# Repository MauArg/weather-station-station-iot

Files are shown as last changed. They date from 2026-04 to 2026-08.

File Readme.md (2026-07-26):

# Infraestructura — Weather Station

Stack de servicios que corre en la Raspberry Pi.

Link al anemómetro impreso en 3D = https://makerworld.com/en/models/2052859-the-windicator-v1

## Setup inicial (primera vez)

### 1. Variables de entorno
```bash
cp .env.example .env
nano .env   # completar MQTT_PASSWORD
```

### 2. Crear el archivo de passwords de Mosquitto
```bash
docker run --rm -it eclipse-mosquitto:2 \
  mosquitto_passwd -c /tmp/passwd weather \
  | cat > ./mosquitto/config/passwd
```

> ⚠️ `passwd` está en `.gitignore`. Nunca lo commitees — tiene credenciales en texto plano.

### 3. Levantar
```bash
docker compose up -d
```

### 4. Verificar que Mosquitto está funcionando
```bash
# En una terminal — escuchar todos los topics de la estación
docker exec -it mosquitto \
  mosquitto_sub -h localhost -u weather -P TU_PASSWORD -t "station/#" -v

# En otra terminal — publicar mensaje de prueba
docker exec -it mosquitto \
  mosquitto_pub -h localhost -u weather -P TU_PASSWORD \
  -t "station/01/test" -m "hola"
```

Si ves `station/01/test hola` en la primera terminal, el broker está listo.

---

## Operación

```bash
# Ver logs en tiempo real
docker compose logs -f mosquitto

# Reiniciar broker
docker compose restart mosquitto

# Bajar todo
docker compose down

# Bajar y eliminar volúmenes (⚠️ borra datos persistidos)
docker compose down -v
```

---

## Activar service mode en el ESP32

**Vía recomendada: la UI.** El dashboard tiene una vista de *service mode* (botón en la barra superior) que arma la sesión, detecta sola cuándo el nodo está despierto y escuchando, verifica la versión después del flash y desarma. Ver `weather-station-frontend-dashboard/`.

Ahí también están el visor de payloads en vivo, el estado por sensor, el margen del buffer MQTT y el indicador de batería con semáforo de riesgo de flasheo.

### Por línea de comandos (fallback si la UI o el backend están caídos)

```bash
# Desde la Raspberry Pi
docker exec -it mosquitto \
  mosquitto_pub -h localhost -u weather -P TU_PASSWORD \
  -t "station/01/cmd" -r \
  -m '{"cmd":"maintenance","timeout_min":15,"issued_at":"'$(date -u +%FT%TZ)'"}'
```

El ESP lo recibirá en el próximo ciclo de wake. Para saber cuándo está listo **no hace falta hacerle ping**: publica en `station/01/status` un `service_mode_active` al entrar y un `service_mode_alive` cada 30 s con el `remaining_sec`, así que alcanza con escuchar ese topic:

```bash
docker exec -it mosquitto \
  mosquitto_sub -h localhost -u weather -P TU_PASSWORD -t "station/01/status" -v
```

Una vez en service mode, flashear desde PlatformIO:
```bash
pio run -e ota_production -t upload     # el que va a campo (LOG_LEVEL=0)
pio run -e ota_development -t upload    # debug (LOG_LEVEL=2, paga 2 s por wake)
```

Y al terminar, **limpiar el retenido** — si no, el nodo se queda despierto hasta que venza el timeout:
```bash
docker exec -it mosquitto \
  mosquitto_pub -h localhost -u weather -P TU_PASSWORD -t "station/01/cmd" -r -m ''
```

---

## Pipeline completo de datos (actualizado 2026-07-11)

Los bloques de **InfluxDB** y **N8N** en `docker-compose.yml` están comentados porque esos servicios **ya están corriendo, pero no acá** — no en la Raspberry Pi de la estación, sino repartidos así:

```
ESP32 ──MQTT──▶ Mosquitto (Docker, esta RPi)
                      │
                      ▼
                 N8N (host de esta RPi, NO en Docker)
                 MQTT Trigger → Code (Line Protocol) → HTTP Request
                      │
                      ▼
              InfluxDB v2 (Docker, NAS 192.168.18.251)
                      │
                      ▼
                Grafana (Docker, NAS 192.168.18.251, puerto 3000)
```

- **NAS (192.168.18.251)**: InfluxDB v2 (imagen fijada a `influxdb:2` — **nunca** `influxdb:latest`, la v3 Core tiene ventana de consulta de 72h, inutilizable para histórico meteorológico) y Grafana, ambos en Docker sobre una red interna `iot-net`, con datos persistidos en `/mnt/disco/influxdb` y `/mnt/disco/grafana`. Hay un override de systemd (drop-in) que hace que Docker espere a que el mount NFS esté listo antes de arrancar — sin eso, los contenedores fallan en boot si el NFS tarda en montar.
- **N8N** corre directo en el host de esta Raspberry Pi (no dockerizado), no en el `docker-compose.yml` de este repo.

⚠️ Los `docker-compose.yml` / configuración del lado del NAS (InfluxDB, Grafana) todavía no están versionados en ningún repo de este proyecto — viven solo en el NAS. Pendiente de incorporar a git si se quiere que el NAS también sea reproducible desde acá.

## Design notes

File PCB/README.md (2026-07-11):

# PCB — exports de fabricación

Exports de fabricación (capas etch/copper/mask/silk en PDF, y SVG) para la PCB v2, generados desde los proyectos Fritzing en la raíz de este repo (`Main PCB - Estación Meteorológica - IoT_v1.4.fzz`, `Aux PCB - Estación Meteorológica - IoT_v1.2.2.fzz`).

Fabricadas caseramente: PCB FR4 simple faz, transferencia de tóner + cloruro férrico. Ver `../componentes_y_conexiones.md` → "PCB v2 — en fabricación" para el estado del armado y el layout completo (asignación de holes, GPIOs, conectores JST).

- `Main 1.4/` — placa principal (ESP32, INA219×2, step-up boost, switching de rails).
- `Aux 1.2/` — placa auxiliar de conectores JST.
- `Main 1.4/Intento1/`, `Main 1.4/Intento2/` — iteraciones sucesivas del export de fabricación de la placa principal.

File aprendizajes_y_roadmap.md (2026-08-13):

# Aprendizajes, decisiones y roadmap

> Migrado desde el proyecto legacy en la UI de Claude (Project Knowledge) el 2026-07-11. Contenido de diseño/ingeniería que no encaja en `componentes_y_conexiones.md` (estado actual de hardware) ni en `Readme.md` (operación de infra). Ver también `../STATUS.md` para el estado vivo resumido.

---

## Subsistema de viento (dirección) — en definición

**Anemómetro — resuelto y estable:**
Modelo base: [The Windicator V1](https://makerworld.com/en/models/2052859-the-windicator-v1) (MakerWorld) — diseño integrado anemómetro + veleta, 2× rodamientos 608ZZ. El eje interior es fijo; el cuerpo exterior (veleta) rota alrededor de él — **no al revés** (esto descarta cualquier approach de montaje de eje fijo para la veleta, ver abajo).

- Sensado: reed switch + 3 imanes (uno por brazo de cazoleta). Radio brazo = 130mm centro a centro.
- Debounce: 2ms (soporta hasta ~500 pulsos/s).
- Factor de calibración ≈ 0.218 m/pulso (2π × 0.130m × 0.8 eficiencia ÷ 3 imanes).
- GPIO2, interrupt.
- Diseño/calibración lista en papel — **pendiente armado mecánico y prueba en campo** (no se empezó todavía, ver `componentes_y_conexiones.md` → "Estado actual en campo").

**Dirección — AS5600 vuelve a ser candidato fuerte (actualizado 2026-07-25):**
La conclusión previa (imanes disponibles son axiales, incompatibles con el AS5600) queda corregida: el módulo AS5600 vino con un imán chico que no se había notado antes. Mau ya soldó los conectores dupont del módulo para probarlo en banco con un Arduino Mega — primero "a mano" (rotando el imán frente al sensor sin la veleta montada, mirando magnet-detected/AGC/magnitude por I2C) y después una prueba de concepto con la veleta montada. Todavía no está confirmado si ese imán es diametral o si el AS5600 tolera algo distinto de lo asumido originalmente — eso es justo lo que la prueba de banco va a determinar, no asumir el resultado.

Contexto original del problema, vigente como fallback si la prueba de banco no lo resuelve:
El approach con AS5600 (sensor de efecto Hall angular, I2C 0x36) requiere un imán **diametralmente magnetizado** (N/S en caras opuestas del disco). La conclusión anterior era que solo había imanes de magnetización **axial** disponibles (polos en las caras planas), y que conseguir uno diametral ~6mm N45 en Argentina (MercadoLibre, local) resultaba difícil. Un imán anillo con diámetro interior >8.25mm también es difícil de conseguir localmente.

**Alternativa (plan B si el AS5600 no resuelve en banco) — disco óptico Gray code:**
3× sensores IR reflectivos TCRT5000 (del kit Sunfounder "Tracking Sensor") sobre un disco con patrón Gray code. Da posición **absoluta** (8 posiciones, resolución 45°) inmediatamente al despertar de deep sleep — resuelve la limitación de posición relativa del AS5600 (que necesitaría recalibrar en cada wake). Operación pulsada (2ms cada 10s, duty cycle 0.02%) reduce el consumo promedio a ~0.018mA.

- GPIO expander PCF8574 (I2C 0x20, sin conflicto de bus) lee las 3 líneas digitales (P0–P2).
- GPIO20 controla LED_EN vía transistor BC337.
- Un segundo cable UTP (6 de los 8 pares: VCC, GND, DO1, DO2, DO3, LED_EN) va del Windicator a la caja estanca.
- Mau tiene 1 sensor TCRT5000; necesita 2 más (más fácil de conseguir localmente que el imán diametral).

---

## Aprendizajes técnicos (no cubiertos en otros documentos)

- **DHT11 (y por extensión DHT22) necesita ~1s de estabilización** después de encender Rail B antes de poder leer.
- **Boost converter → pin 5V del ESP32 es el path de alimentación correcto.** Conectar la batería directo a un LDO falló por voltaje de dropout insuficiente con una LiPo a 3.7V.
- **AS5600 no es compatible con el montaje de eje fijo del Windicator V1** — el diseño tiene el eje interior fijo y el cuerpo exterior rotando, lo inverso de lo que ese approach de montaje asume.
- **GitHub devuelve 404 (no 403) para repos privados sin autenticar** — no es una falla de red, hay que reconocerlo como "repo privado, necesita auth" en vez de reintentar la conexión.
- **Grafana: las variables "Constant"** requieren guardar el dashboard explícitamente para que el cambio se aplique.

- **El volumen de InfluxDB no es el recurso escaso; el barrido de consultas sí** (medido 2026-08-09, a raíz de la duda por el volumen que genera live mode). Con live corriendo 7 h en los días soleados el ritmo pasa de ~1.350 a ~5.760 payloads/día — **4,3×**, no 12×, porque live se auto-limita a las horas de excedente. A 26 campos y con la compresión TSM sobre floats de variación lenta son **~170 MB/año, ~1,7 GB en 10 años**: sobre el disco de 4 TB del NAS, 0,04%. Aunque la estimación se equivoque por 10×, sigue siendo irrelevante.

  Lo que sí escala mal con los años es **escanear millones de puntos de 5 s para un gráfico de rango largo**. El disparador a vigilar es ese, no el disco: **si un dashboard de rango largo empieza a tardar, la respuesta es una tarea de downsampling** (agregados de 1 min o 1 h para rangos largos, crudo sólo para lo reciente), no borrar datos ni achicar live mode. Hoy no hace falta.

  Dos cosas más del mismo relevamiento: la **retención del bucket es infinita**, que para una estación meteorológica es probablemente lo correcto —la serie histórica larga *es* el producto— pero conviene que sea una elección consciente. Y la **cardinalidad crece por el tag `firmware`**, una serie nueva por versión para siempre (28 al 2026-08-09). Irrelevante en capacidad —InfluxDB aguanta millones— pero es el tag que ya rompió cinco queries con `last()` devolviendo un resultado por serie; toda query nueva tiene que contemplarlo.

- **Un campo nuevo en la telemetría no aparece solo en InfluxDB.** El workflow de N8N arma Line Protocol desde un `fieldMap` explícito y descarta en silencio lo que no conoce. `log_active`/`log_count` existían desde el `1.3.0` y nunca llegaron; se descubrió recién en agosto al buscar `live_seq`. Ese script **no está versionado en ningún repo** (vive sólo en el NAS). Regla: al agregar un campo al payload, **decidir explícitamente** si va a N8N en la misma tanda. Detalle en `../STATUS.md`.

  La regla es decidir, no agregar todo: lo que hay que evitar es que un campo se pierda sin que nadie lo note, no que InfluxDB tenga todo. **Caso resuelto así (2026-08-09): `next_s` NO se agregó.** Lo consume el backend leyendo el payload MQTT directo, así que la funcionalidad no depende de InfluxDB; y como dato histórico es derivable (la presencia de `live_seq` ya marca la sesión, y los deltas entre timestamps dan la cadencia real, que además es más honesta que la intención del nodo) y vale 60 en el 99% de los puntos. **Reevaluarlo cuando lleguen los tiers**: ahí `next_s` pasa a valer 60/300/1800 según el voltaje del pack y deja de ser derivable de los otros campos.

- **Comparar una magnitud con ciclo diurno entre dos firmwares exige controlar la hora del día.** Al validar el cambio de `DHT_WARMUP_MS` el delta DHT22−DS18B20 parecía haberse corrido 0,3 °C; separando por franja horaria, el firmware **sin cambiar** daba lo mismo en esa franja. Era el transitorio de enfriamiento de la tarde, donde el DHT22 (masa térmica chica) sigue la caída más rápido que el DS18B20. Es el mismo error de método que ya se había cometido con la posición del sniffer WiFi, en otra dimensión.

- **El rollback de OTA está compilado pero desarmado, y `esp_ota_mark_app_valid_cancel_rollback()` no hace lo que parece.** `CONFIG_BOOTLOADER_APP_ROLLBACK_ENABLE=y` en el sdkconfig del core, o sea que una imagen recién flasheada arranca en `ESP_OTA_IMG_PENDING_VERIFY` y el bootloader la revertiría si nadie la valida. Pero el core de Arduino la valida solo: `initArduino()` (en `esp32-hal-misc.c`, antes de `setup()`) llama a `verifyOta()` —función *weak* que devuelve `true` por defecto— y marca la imagen válida. **Toda imagen que bootee se acepta sin chequear nada.** Además, la llamada que había en `ArduinoOTA.onEnd()` corría en el firmware *viejo* y marcaba válida la partición vieja, no la nueva; se eliminó.

  Lo que sí sigue protegido sin hacer nada: un flash **cortado a la mitad** deja una imagen que no pasa la validación del bootloader, y arranca la partición anterior. El agujero es la imagen **completa pero rota**, que bootea y se acepta.

  **Evaluado a fondo el 2026-07-27 — decisión: no se implementa por ahora.** El análisis quedó acá porque la conclusión no es obvia y no conviene re-derivarla.

  **`verifyOta()` es la palanca equivocada**, al contrario de lo que decía la nota original de este mismo bullet. Ese hook corre dentro de `initArduino()`, *antes* de `setup()`: sólo puede juzgar con lo que se sabe en el primer arranque de la imagen, cuando todavía no corrió nada del firmware. Un chequeo de I2C ahí responde "¿está el hardware?", no "¿sirve este firmware?". La palanca real es la otra función weak del mismo bloque, **`verifyRollbackLater()`**: devolviendo `true` el core saltea la validación entera y la decisión queda del lado de la aplicación, para tomarla más tarde con el runtime ya levantado. Ninguna de las dos está declarada en un header — son símbolos C, hay que definirlas con `extern "C"`.

  **El bloqueante que parecía haber, no existe.** `esp_ota_begin()` devuelve `ESP_ERR_OTA_ROLLBACK_INVALID_STATE` si la imagen corriendo está en `PENDING_VERIFY`, lo que dejaría una ventana de OTA abierta pero inútil. No aplica: el `Update` de Arduino no pasa por `esp_ota_begin()` — usa `esp_ota_get_next_update_partition()` + escritura cruda de partición + `esp_ota_set_boot_partition()` (`Updater.cpp`), y ese último no tiene ese código de error. **Con la imagen sin confirmar, el OTA sigue funcionando**, así que diferir la validación es seguro.

  **El criterio de salud no debería ser I2C** sino "la imagen llegó a abrir su propia ventana de OTA", con "llegó a dormir limpio" como red de contención. Las dos propiedades son locales y **un fallo de WiFi cuenta como sano**, que es lo que evita el falso positivo con el ~17% de ciclos que no conectan. Habría que confirmar en cinco puntos: después de `_setupOTA()` en `serviceMode_run()`, en `goToDeepSleep()`, en `serviceMode_exit()` (que llama a `esp_deep_sleep()` directo) y antes de los dos `ESP.restart()` — sin este último, un comando `reboot` durante la ventana sin confirmar dispararía un rollback. La llamada tiene que ir guardada detrás de un `esp_ota_get_state_partition() == ESP_OTA_IMG_PENDING_VERIFY` explícito: sin eso, cada deep sleep podría escribir en `otadata`, que son ~1440 escrituras/día sobre una partición de 8 KB.

  **Por qué no se implementa igual**: de los bugs reales que aparecieron en este firmware — loop de `reboot`, timeout de service mode que no acotaba, overflow del buffer MQTT, warmup del DHT que nunca corría — el rollback no habría atrapado **ninguno**; todos completaban un ciclo limpio. Sólo cubre "crashea antes de abrir el OTA", y como el post-OTA reintenta service mode en cada boot, la ventana real de brickeo es angosta (un crash en `Wire.begin()` o `connectWiFi()`). A cambio agrega un modo de falla insidioso: si un camino de salida nuevo se olvida de confirmar, el nodo revierte firmware solo, semanas después. El argumento a favor sigue siendo válido y es no-técnico — el plan B de un brickeo es subir al techo y **abrir la caja estanca**, el mismo sellado que se monitorea con el DHT22 — así que esto se reconsidera si el firmware se vuelve más riesgoso de flashear.

  **Sin verificar**: el sdkconfig tiene `CONFIG_BOOTLOADER_SKIP_VALIDATE_IN_DEEP_SLEEP=1` y no se pudo determinar offline si el chequeo de `PENDING_VERIFY` del bootloader corre al despertar de deep sleep (el paquete de PlatformIO trae sólo headers, no las fuentes del bootloader). El diseño de arriba está armado para no depender de eso, pero si se implementa hay que confirmarlo en banco.

(Los aprendizajes sobre I2C/pull-ups externos, `system_mW` no siendo consumo real, cold solder joints, InfluxDB `:2` fijo, y el drop-in de systemd para NFS ya están documentados en `componentes_y_conexiones.md`, `../i2c-bus-lockup-investigation.md` y `Readme.md` respectivamente.)

---

## Herramientas y recursos

- **Desarrollo:** VSCode + PlatformIO. Build flags ESP32-C3 SuperMini: `ARDUINO_USB_CDC_ON_BOOT=1`, `ARDUINO_USB_MODE=1`.
- **Pipeline de datos:** ver `Readme.md` → "Pipeline completo de datos".
- **Referencias de hardware:** kit Sunfounder (DHT11, DS18B20, raindrop sensor, fotoresistor, reed switch, TCRT5000 "Tracking Sensor", PCF8591 ADC); módulo MPPT CN3791; transistores NPN BC337; expansor I2C PCF8574; conectores Wago 221 lever; conectores JST XH; prensaestopas PG-7 y PG-9.
- **Sourcing:** Embalse, Córdoba, Argentina — ferreterías locales para mecánica, MercadoLibre para electrónica. Algunos componentes (imanes diametrales, imanes anillo) son difíciles de conseguir localmente.
- **Impresión 3D:** Mau no tiene impresora propia — depende de un familiar en Buenos Aires para las piezas impresas, lo que agrega tiempo de espera a cualquier pieza nueva.

---

## Roadmap — "en el horizonte"

Reconciliado con el estado real al 2026-07-11 (el snapshot original venía del proyecto legacy en la UI y estaba desactualizado en varios puntos — marcado abajo).

- ✅ **Armado físico del prototipo v1** — hecho (dos perfboards, con cold solder joints ya en gran parte resueltos). El snapshot original lo listaba como pendiente; ya no lo está.
- 🔄 **PCB v2 (FR4 casera, transferencia de tóner + cloruro férrico)** — en fabricación. Main + Aux perforadas, soldadura en curso. Pendiente: terminar de soldar, limpiar flux, enmascarar headers hembra, aplicar flux protector + barniz dielectrico, curar, recién ahí instalar módulos enchufables (INA219, ESP32). Ver `componentes_y_conexiones.md` → "PCB v2 — en fabricación".
- ✅ **Perforación de la caja estanca** (ventana PET para fotoresistor, prensaestopas) — hecha, sistema desplegado y operativo.
- ✅ **Backend + frontend custom** — hecho: `weather-station-backend-service` (Go) y `weather-station-frontend-dashboard` (React/Vite), ya no es "un amigo capaz hace el frontend" como decía el snapshot original.
- ⏳ **Resolución de dirección de viento** — AS5600 vuelve a ser candidato fuerte (imán chico encontrado en el módulo, no notado antes); en validación de banco con Arduino Mega desde 2026-07-25. Óptica (2 sensores TCRT5000 más) sigue como plan B.
- ⏳ **Armado mecánico del Windicator** (anemómetro + veleta) — impreso en PLA, pendiente de armar y probar en campo.
- ❓ **Montaje del panel solar** (placa de respaldo policarbonato/fenólico, sellado con silicona, bracket a 45°) — estado sin confirmar en esta sesión; el sistema ya reporta datos solares (INA219 solar) así que probablemente esté al menos parcialmente instalado.
- ❓ **Mejora del Stevenson screen** (protección lateral contra sol, ventilación forzada) — estado sin confirmar. Se sabe que el wrap de aluminio en el mástil redujo contaminación térmica (2.04°C de mejora confirmada por análisis de datos) pero generó un efecto espejo que refleja radiación hacia el BMP180.
- ⏳ **Modos adaptativos de firmware** (día/noche por voltaje solar, tiers de energía por voltaje de batería) — **verificado 2026-07-29: no está implementado.** `src/battery.h` existe pero está vacío (0 bytes), `SLEEP_INTERVAL_SEC` es fijo, y `sensors_railsOn()` enciende los dos rails incondicionalmente (el TODO sigue ahí). Los umbrales de `componentes_y_conexiones.md` son diseño en papel. **Corrección de premisa**: los tiers no ahorran en deep sleep — GPIO7/GPIO8 no son RTC GPIOs en el ESP32-C3, así que al dormir quedan sin drive y el pull-down de 9,9 kΩ corta ambos rails solo. El ahorro real está en T3/T4, que cambian el intervalo de sleep.
- ✅ **Bajo consumo — dos fixes en campo (2026-07-29)**: INA219 en power-down entre ciclos (`1.4.0`) y warmup del DHT22 en paralelo con la red (`1.5.0`). Ver `../STATUS.md` → "Power management".
- ⏳ **Calibración de lluvia en Grafana** — `rain_wet_ref=0.3` sigue siendo un placeholder, falta dato real de lluvia intensa.
- ⏳ **Medir el consumo de reposo con multímetro** — ~3,2 mA de los 5,10 mA totales están sin explicar (63% del presupuesto). No hay firmware que lo resuelva: el INA219 se apaga al dormir. **Es la medición de mayor valor pendiente.** **Procedimiento de banco listo para ejecutar en [`medicion_consumo_reposo.md`](./medicion_consumo_reposo.md)** (2026-08-11): tres mediciones, empezando por las que no tienen ráfagas de WiFi porque la SuperMini se desenchufa del zócalo sin desoldar. Contexto en `componentes_y_conexiones.md`.
- ⏳ **Integrar la energía de la ventana activa en el firmware** (`active_mAs` + `awake_ms` en el payload, promediado por hardware del INA219) — acordado 2026-08-02, sin empezar. Ver la sección dedicada más abajo. Hacerlo **después** de medir el reposo.
- ❓ **Alcance de WiFi** — faltaban ~5m de cobertura; se subió la potencia de transmisión del TP-Link AX3000 a "High" como primer intento, resultado sin confirmar en esta sesión.

---

## Medir la energía de la ventana activa en vez de una muestra suelta (acordado 2026-08-02, sin empezar)

**Qué está mal hoy.** `system_mW` es **una** lectura del INA219 de 532 µs tomada en un punto arbitrario de la ventana despierta de ~2,3 s. Cae aleatoriamente dentro o fuera del burst de transmisión de WiFi, así que es un pico y no un promedio — cubre el **0,02%** de la ventana. Sirve para diagnosticar el sag; no sirve para presupuestar energía.

Eso rompió cosas río abajo: el balance energético del dashboard restaba ese pico (continuo en apariencia) contra la potencia del panel, que sí es continua, y daba déficit el 56% del día con buena luz. Se resolvió del lado del backend cambiando el medidor por un estado derivado (ver `../STATUS.md` → 1.2.0), pero **el dato crudo sigue siendo un pico**.

### Por qué va en el nodo y no en el backend

La regla del proyecto es que el cómputo vive en el backend — el punto de rocío se calcula ahí, no en el nodo, aunque el ESP32 podría. **Esto no la viola**, y la distinción importa:

- El punto de rocío es **derivación**: temperatura y humedad viajan enteras en la telemetría, así que el backend tiene toda la información. Se calcula ahí para poder corregir la fórmula sin reflashear.
- La energía de la ventana activa es **adquisición**: la dinámica sub-segundo del burst **no existe en la telemetría**. El nodo publica una muestra; ninguna lógica en el backend recupera lo que nunca se transmitió.

Enunciada mejor, la regla es **el nodo es dueño de la adquisición, el backend de la interpretación**. Integrar al ritmo de muestreo que sólo el nodo tiene es adquisición — la misma categoría que "leer el INA219", sólo que 30 veces en vez de una.

(Nota: el nodo ya calcula `pressure_qnh`, que sí es derivación pura. La regla ya se aplica con flexibilidad.)

### Qué publicar

**La integral y la ventana por separado, no el promedio ya masticado:**

| campo | qué es |
|---|---|
| `active_mAs` (o mWh) | carga/energía integrada sobre la ventana despierta |
| `awake_ms` | cuánto duró esa ventana |
| `system_mW` | **se mantiene** — el instantáneo sigue sirviendo para el sag |

Con esos dos el backend calcula promedio, ciclo de trabajo y mWh/día, y puede cambiar de criterio sin reflashear. Si el nodo manda sólo "el promedio", se pierde la capacidad de recalcular — que es justo la razón por la que el punto de rocío vive en el backend.

**Beneficio concreto**: hoy el ciclo de trabajo (3,6%) es una constante hardcodeada que ya cambió entre firmwares, y por eso el backend se negó a usarla para prorratear. Con `awake_ms` en el payload esa corrección pasa a ser honesta.

Presupuesto de payload: hay ~170 B de margen sobre 741 B, así que entran de sobra.

### Promediado por hardware del INA219

El registro de configuración (`0x00`) tiene dos campos de ADC independientes, **BADC** (bits 10-7, bus) y **SADC** (bits 6-3, shunt), con la misma codificación:

| bits | modo | conversión |
|---|---|---|
| `0011` | 12 bit, 1 muestra | 532 µs ← **lo que corre hoy** |
| `1101` | 32 muestras | 17,02 ms |
| `1111` | **128 muestras** | **68,10 ms** |

El chip promedia internamente; se lee un registro y sale la media. Cero costo de CPU.

**Lo que lo vuelve realmente útil**: en modo continuo el INA219 convierte de corrido. Leyendo cada ~70 ms durante los 2,3 s despierto salen **~33 promedios consecutivos que no se solapan y cubren casi el 100% de la ventana**. Eso no es "tomar varias muestras": es una integral completa.

**Obstáculos conocidos**, en orden de fastidio:

1. `Adafruit_INA219 @ 1.2.1` **no expone el promediado**. Los `setCalibration_*()` arman el registro con `12BIT_1S_532US` hardcodeado. Hay que escribir el registro `0x00` por `Wire` **después** de llamar a `setCalibration_*()`, o el calibrado lo pisa. El header define constantes tipo `INA219_CONFIG_SADCRES_12BIT_128S_69MS` — **verificar los nombres exactos en el header instalado**, no están confirmados.
2. Durante esa ventana el ESP32 está ocupado con WiFi. Un loop bloqueante de 2,3 s no es viable. Salidas: leer en los puntos de transición (antes de WiFi, tras conectar, tras publicar, antes de dormir) acumulando `P × Δt`, o disparar las lecturas desde un timer.
3. Subir el tiempo de conversión alarga el `sensors_read()`; medir el impacto sobre la ventana despierta, que es justamente lo que se está tratando de no inflar.

### Verificación contra el código (2026-08-11) — cuatro correcciones al diseño de arriba

Revisado el firmware `1.18.0` y la librería instalada (`Adafruit_INA219 @ 1.2.1`) antes de implementar. Lo de arriba se escribió en papel; esto es lo que dice el código.

**1. Hoy el INA219 está en power-down durante todo el burst de WiFi.** Es el hallazgo que cambia el diseño. La secuencia real del ciclo normal:

| línea | qué pasa | INA219 |
|---|---|---|
| `main.cpp:65` | `Wire.begin()` | power-down, heredado del ciclo anterior |
| `main.cpp:101` | `sensors_railsOn()` | power-down |
| `main.cpp:103-107` | WiFi + MQTT + espera del retenido (~1,3-2 s) | **power-down** |
| `main.cpp:110` | `sensors_init()` → `begin()` → `setCalibration_32V_2A()` | recién acá arranca a convertir |
| `main.cpp:446` | `sensors_read()` — la muestra publicada | continuo, 532 µs |
| `main.cpp:573` | `sensors_sleepMonitors()` | power-down otra vez |

El `1.4.0` los puso en power-down para ahorrar, el registro de configuración sobrevive el deep sleep (cuelgan del 3V3 siempre alimentado) y nada los despierta hasta `begin()`, que corre **después** de la red.

**Corrige la premisa de la sección de arriba**: la muestra no "cae aleatoriamente dentro o fuera del burst". Cae **sistemáticamente en la fase tranquila**, en la cola de lectura de sensores con la radio asociada pero ociosa. Sesga bajo de forma consistente, no aleatoria — que es peor para presupuestar, porque un sesgo sistemático no se promedia solo.

**Consecuencia**: cualquier versión de esto empieza por despertar el INA219 arriba de `setup()`. Costo de tenerlo convirtiendo toda la ventana en vez de sólo la cola: ~1 mAh/día sobre 122, un 0,8%.

**2. `powerSave()` preserva los bits de promediado; `begin()` los destruye.** `powerSave()` hace read-modify-write sobre los bits 2:0 nada más (`Adafruit_BusIO_RegisterBits(&config_reg, 3, 0)`), así que la configuración de ADC sobrevive el ciclo dormir/despertar. Pero `setCalibration_32V_2A()` reescribe el registro **entero** con `BADCRES_12BIT | SADCRES_12BIT_1S_532US` hardcodeado (`Adafruit_INA219.cpp:265`). **El override va después de cada `begin()`**, no una sola vez.

**3. Obstáculo 1: resuelto.** Los nombres de constantes que figuraban como "sin confirmar" existen tal cual en el header instalado — `INA219_CONFIG_SADCRES_12BIT_128S_69MS`, `INA219_CONFIG_BADCRES_12BIT_128S_69MS`. Sigue sin haber API pública para escribir config, pero un `Wire` crudo al registro `0x00` alcanza.

**4. El "~33 promedios que cubren casi el 100% de la ventana" es optimista como está escrito.** En `SANDBVOLT_CONTINUOUS` el chip alterna shunt y bus, así que los tiempos se **suman**: con 128 muestras en los dos, el loop es 68,1 + 68,1 = **136 ms** y la corriente se integra sólo el **50%** del tiempo → ~17 promedios en 2,3 s, no 33. Para llegar a los 33 con ~99% de cobertura de corriente hay que dejar **SADC en 128S y BADC corto** — asimétrico, que la sección de arriba no especificaba.

**Y el obstáculo 3 se disuelve solo.** El temor de que subir el tiempo de conversión inflara `sensors_read()` no aplica si el chip se despierta arriba de `setup()`: para cuando llega la lectura ya lleva ~2 s convirtiendo de corrido y hay decenas de promedios completos esperando en el registro. No agrega latencia.

**Ojo con una trampa al implementar el paso 2**: la librería no consulta el bit CNVR (conversion ready), así que dos lecturas más rápidas que el tiempo de conversión devuelven **el mismo valor**. En un loop de integración eso sería doble conteo — hay que espaciarlas por lo menos un tiempo de conversión.

**5. La mina de N8N no se dispara con el promediado por hardware** (confirmado el 2026-08-13, cerrando el "a confirmar" de `../STATUS.md` → pendiente 3 del indicador de SoC).

El riesgo anotado era: N8N escribe `${p.solar_mW}i` y `${p.system_mW}i` como enteros de Line Protocol, y eso funciona **por casualidad** porque `ina219_powerMultiplier_mW = 2` con la calibración 32V/2A. Un valor fraccionario como `256.4i` es inválido y **InfluxDB rechaza el write entero**.

**No aplica al promediado por hardware.** El promediado ocurre *dentro del ADC del chip*, antes de que calcule el registro POWER, que sigue siendo un entero de 16 bits. `getPower_mW()` hace `getPower_raw() * 2`, así que la potencia sigue saliendo múltiplo entero de 2. **Line Protocol válido, sin tocar N8N.**

> ⚠️ **Sí aplicaría a un promedio por software.** Si en el paso 2 se acumula y se divide en el firmware, o si alguna vez se cambia la calibración a `32V_1A` (`powerMultiplier = 0.8`) o `16V_400mA` (`= 1.0` pero con `currentDivider` distinto), la potencia deja de ser entera y hay que arreglar N8N **antes** de flashear. Los campos `*_mA` no corren riesgo: `getCurrent_mA()` divide por 10 y ya emite fraccionarios hoy, así que N8N los escribe como float.

**Alcance acordado con Mau (2026-08-11)**: se hace en dos pasos, primero el promediado por hardware sólo-firmware y después la integración de la ventana completa. Pero **antes va la medición del reposo con multímetro** — ver `medicion_consumo_reposo.md`, que tiene el procedimiento listo.

**Actualización (2026-08-13)**: la sesión del indicador de SoC agregó un orden propio — *backend primero, firmware después*, y **el backend ya está hecho y desplegado** (ventana compartida con latch histerético, backend `1.5.0`). No contradice lo de acá: el promediado ataca ruido de muestra en escala de ms y esa lógica detecta eventos sobre ventanas de 15 min, así que son complementarios y el firmware la mejora sin obligar a recalibrar nada. La fila queda: **reposo con multímetro → paso 1 (firmware) → paso 2 (cadena completa)**.

### ⚠️ Advertencia de prioridad

Esto instrumenta **44,7 mAh/día** (la ventana activa). Los otros **77,7 mAh/día** — el 63% del presupuesto — están sin instrumentar y sin explicar; ver `componentes_y_conexiones.md` → "El reposo pesa más que la ventana activa". Y el INA219 **no puede** medirlos, porque el propio firmware lo pone en power-down al dormir.

**Antes de encarar esto conviene medir el reposo con multímetro.** Es cinco minutos y contesta la mitad grande del presupuesto.

---

## Evolución candidata: nodo "offline" con RTC + almacenamiento local (idea de Mau, 2026-07-27)

Surgida mientras se diseñaba el sistema de logs. La idea: un nodo que **no depende de la red** — recolecta datos, los guarda localmente con timestamp real, y el operador se acerca cada muchos días o meses a descargarlos por Bluetooth. Caso de uso concreto: Mau tiene un terreno sin servicios donde se podría instalar uno.

Es un cambio de categoría, no una feature: el nodo pasa de "sensor conectado" a "data logger con sincronización ocasional". No aplica al nodo actual — aplica a una placa v3.

### El premio real es energético, no de conectividad

En el nodo actual el WiFi domina todo: **3,3 s despierto** a 80-140 mA por ciclo (medido en campo el 2026-07-28; la cifra de "~10 s" que figuraba acá estaba mal por 3×). Un ciclo sin red —despertar, leer sensores, escribir a almacenamiento local, dormir— es del orden de 1 s a ~20 mA, y encima se ahorra la espera del comando retenido. Es más de un orden de magnitud de carga por ciclo, no los dos que decía la estimación original. Eso es lo que habilita el "ultra low power" que mencionaba la idea: meses de autonomía, o el mismo tiempo con un panel mucho más chico. La descarga ocasional por BLE se paga una vez cada muchos días, no 1440 veces por día.

### RTC con pila propia — encaja en el nodo actual

- **No consume GPIOs**: es I2C, cuelga del bus que ya existe (donde ya están los dos INA219). Un DS3231 vive en 0x68, sin conflicto con 0x40/0x41.
- **Cuidado con el consumo**: un DS3231 alimentado consume ~100-200 µA, contra un objetivo de deep sleep de <50 µA. Puesto en el rail always-on arruinaría el presupuesto por 4×.
- **La topología correcta ya existe en la placa**: colgarlo de un **rail conmutado** (Rail A). Mantiene la hora con su pila de botón mientras está sin alimentar, y se energiza sólo durante el wake para leerlo. Costo en deep sleep ≈ 0. Es exactamente lo que la placa ya hace con los otros sensores.
- **A verificar antes de comprar**: en el DS3231 la interfaz I2C se deshabilita cuando corre desde Vbat. Para este uso da igual (sólo se lee con Vcc presente), pero hay que confirmarlo en el datasheet.
- **Beneficio secundario que no es menor**: el timer de deep sleep del ESP32 corre sobre un oscilador RC interno con ±5% de precisión — sobre un día son ±72 min de deriva. Un RTC da alineación a hora de pared real, y de paso vuelve innecesario el esquema de interpolación de timestamps del sistema de logs.

### microSD — bloqueada por pines en la placa actual

**No entra.** Sólo quedan libres **GPIO20 y GPIO21** (ver `componentes_y_conexiones.md` → "GPIOs asignados"; GPIO9 es el botón BOOT físico y no se puede usar). SPI necesita 4 pines (MOSI, MISO, SCK, CS) y SDIO en modo 1-bit necesita 3 más CS. Encima GPIO20 ya está pre-asignado al `LED_EN` del PCF8574 si se va por la vía óptica para dirección de viento.

Además, aun con pines disponibles: las escrituras a SD son ráfagas de 50-100 mA y las tarjetas son notoriamente frágiles ante cortes de energía a mitad de escritura — mal match para un nodo solar.

**Alternativa que sí entra sin tocar un solo pin**: una FRAM o EEPROM I2C, colgada del mismo bus. Una FM24CL64 (8 KB de FRAM) tiene endurance prácticamente infinita (10¹² ciclos) contra el millón de una EEPROM; una 24LC512 da 64 KB. A ~50 B por muestra, 64 KB son ~1300 muestras: 9 días a una muestra cada 10 min, o ~54 días a una por hora. Para el nodo offline probablemente haya que ir a algo más grande o encadenar varios chips, pero la topología es la correcta y el costo en GPIOs es cero.

### Bluetooth para la descarga

El ESP32-C3 tiene BLE 5.0, así que el nodo actual ya tendría la radio. Lo interesante es del lado del operador: **Web Bluetooth desde Chrome en Android permitiría reusar el dashboard React que ya existe**, sin escribir una app nativa. Limitación conocida: Web Bluetooth no funciona en Safari/iOS.

Números para dimensionar: 6 meses a una muestra cada 10 min son ~26.000 muestras ≈ 1,3 MB. A la velocidad realista de BLE en el C3 (~20 KB/s) es alrededor de un minuto de descarga. Perfectamente viable.

### Lo que habría que resolver del lado del backend

El pipeline actual asume datos **en vivo**. Ingerir un lote de muestras de hace seis meses es un camino distinto: hay que aceptar backfill histórico, deduplicar contra lo que ya se importó, y decidir qué pasa si el reloj del nodo derivó o se reinició. No es difícil, pero es trabajo que hoy no existe.

---

## Primera captura de logs en campo (2026-07-28) — el ~17% de ciclos perdidos, resuelto

Primera corrida real del sistema de logs contra el nodo con firmware `1.3.0`: **177 eventos, 30 ciclos, nivel 3 (verboso), 0 eventos pisados**. Esto cierra la pregunta que motivó todo el sistema. Los números de acá salen de esa captura; no hace falta re-derivarlos.

### El fallo no es WiFi

**WiFi asoció en el primer intento las 30 veces**, incluso con la señal degradada: 30 `LOG_WIFI_TRY`, 30 `LOG_WIFI_OK`, **cero** `LOG_WIFI_FAIL` y cero `LOG_WIFI_GIVEUP`. La hipótesis anterior —"el nodo no se asocia por señal marginal"— queda descartada como mecanismo.

Lo que falla es la capa **TCP/MQTT**, y correlaciona fuerte con el RSSI:

| Ventana | RSSI | Ciclos que intentaron publicar | Fallos | `mqtt.connect()` |
|---|---|---|---|---|
| Degradada | **-73 dBm** | 5 | **3 (60%)** | 399 / 412 / 550 ms, más 2 timeouts |
| Normal | -63 a -66 dBm | 21 | **0** | 32–69 ms |

El código de error es `state -4` = `MQTT_CONNECTION_TIMEOUT` (`PubSubClient.h:45`). El mecanismo: el handshake MQTT pasa de **~40 ms a 2400–3200 ms** cuando la señal se degrada —un factor de 60×— y a veces cruza el socket timeout de 5 s, perdiendo el ciclo entero. Tasa global en esta captura: 3 de 26 = 11,5%, consistente con el ~17% histórico.

El `LOG_PUBLISH_FAIL` que apareció decía "¿buffer corto?" con **505 B contra 741 disponibles**: fue una conexión caída a mitad del publish. Ya corregido — la entry ahora distingue las dos causas en su argumento `a`.

### El enlace oscila ~9 dB solo por el ambiente

Confirmado por Mau: entre la ventana degradada y las normales **no hubo ningún cambio de configuración**. La diferencia fue ambiental — una persona moviéndose, una puerta abriéndose. Son 9 dB, casi un orden de magnitud de potencia.

El router (TP-Link Archer) **ya está con la potencia de transmisión al máximo**, y ese fue un parche necesario: en "medium" el nodo directamente no lograba conectarse. O sea que no queda margen de configuración del lado del AP, y la condición marginal no es un caso raro sino el régimen normal de operación.

### El tiempo despierto es 3,3 s, no ~10 s

La cifra de "~10 s despierto" que circulaba por los documentos **estaba mal por 3×**. Mediana sobre 20 ciclos sanos:

| Tramo | Mediana | % del despierto |
|---|---|---|
| boot → primer intento de WiFi | 73 ms | 2% |
| WiFi asociado | 201 ms | 6% |
| MQTT conectado | 40 ms | 1% |
| **red lista → publish** | **3048 ms** | **92%** |
| **Total** | **3300 ms** | |

Es decir: **la red está lista a los ~314 ms y el nodo se queda 3 segundos más con el WiFi asociado y consumiendo**, esperando el comando retenido y el warmup del DHT22. Eso invierte el peso de dos cosas que estaban anotadas con otras proporciones:

- Los **800 ms de `waitForRetainedCommand`** figuraban como "~8% del tiempo despierto". Son **24%**.
- Los **2 s de warmup del DHT22** son el **61%** de toda la ventana despierta.

### Pendientes que salieron de esto

**1. Reintentar `mqtt.connect()` en el ciclo normal.** ⏳ Pendiente, para la sesión dedicada de MQTT. Hoy hay un único intento en `connectMQTT()`: si da timeout, `main.cpp` va directo a `goToDeepSleep()` y el ciclo se pierde. Con WiFi ya arriba —la parte cara, y que nunca falla— y sólo ~800 ms gastados, un segundo intento cuesta a lo sumo otro socket timeout y salva el ciclo. Service mode ya tiene `SERVICE_MODE_MQTT_RETRIES`; el ciclo normal no tiene nada equivalente.

> Ojo con dimensionar el impacto: la segunda captura mostró que el fallo de `connect()` explica ~1,5% de los ciclos, no el grueso de la pérdida. Ver "Segunda captura" abajo.

**2. Mover el rail-on del DHT22 al inicio de `setup()`.** ✅ **Hecho y medido — firmware `1.5.0`, 2026-07-29.** El despierto bajó de 3300 a **2200 ms** (publish absoluto 3365 → 2292 ms), o sea −1073 ms / −33%, ≈ −22 mAh/día. Verificado sobre 116 ciclos sanos; los demás tramos del ciclo quedaron dentro de milisegundos del baseline. Detalle en `../STATUS.md` → "Power management". Efecto secundario importante: el warmup del DHT22 pasó a ser el término que fija el piso del despierto, lo que **anula** el pendiente de acortar `MQTT_RETAINED_WAIT_MS` — documentado en `src/config.h`.

**3. Revisar el presupuesto de reintentos de WiFi.** ⏳ Pendiente. `WIFI_MAX_RETRIES` 3 × `WIFI_TIMEOUT_MS` 15 s da un peor caso de 45 s que está documentado como el costo de un ciclo fallido — pero **nunca ocurrió**: los ciclos fallidos costaron 5,2–6,2 s, y todos fallaron en MQTT, no en WiFi. El presupuesto está dimensionado para un modo de falla que no es el real. Antes de recortarlo conviene capturar una ventana con señal peor todavía, para no optimizar contra una muestra de una sola noche.

---

## Segunda captura de logs en campo (2026-07-29) — `LOG_PUBLISH_OK` no prueba entrega

68 ciclos sobre `1.3.1`, nivel 3, 0 pisados, sin huecos de `boot_count`. Confirmó los tiempos de la primera captura casi exactamente (red lista a 322 ms, red→publish 3047 ms, despierto 3300 ms) y **corrigió la conclusión principal**.

**El número real de pérdida es 42%, no 17%.** 67 ciclos registraron `LOG_PUBLISH_OK` y sólo 39 llegaron. Cruzado contra **dos consumidores independientes** —el backend Go por MQTT directo e InfluxDB vía N8N— que coinciden exactamente en qué llegó: dos caminos separados perdiendo los mismos mensajes ⇒ nunca llegaron al broker.

**El aprendizaje transferible**: `PubSubClient::publish()` devuelve `true` cuando la escritura al socket tuvo éxito. En QoS 0 no hay ack posible, así que eso **no** es evidencia de entrega. El nodo cierra el socket en el mismo milisegundo y apaga la radio 200 ms después; si el segmento TCP necesita retransmisión (RTO del orden de 1-3 s) muere en silencio. Cualquier instrumentación futura que quiera afirmar "se publicó" necesita QoS 1 con PUBACK, o un consumidor que confirme.

**No correlaciona con RSSI**: llegados vs. perdidos tienen distribuciones idénticas de señal, de tiempo de `connect()`, de tamaño de payload y de tiempo despierto.

**Tercera captura (`1.5.0`, 119 ciclos) — dos refinamientos, uno de ellos una corrección:**

- La pérdida se mantiene en **38%**, y el RSSI barrió **10 dB** (-71 a -61) con correlación **cero** (mediana -67 en ambos grupos). La salvedad de la banda angosta queda contestada: no es intensidad de señal.
- **Corrección**: la conclusión de "pérdida independiente y sin memoria" **era incorrecta** — salió de comparar rachas contra una geométrica sobre sólo 67 muestras, donde la desviación quedaba dentro del ruido. Con 112 pares consecutivos, la pérdida **alterna** de forma significativa: `P(perdido | anterior perdido) = 0,279` contra `P(perdido | anterior llegó) = 0,470`, chi² = 3,96 (p < 0,05). **Lección de método**: no declarar "independiente" desde un ajuste de rachas con n chico — el test de correlación a lag 1 tiene mucho más poder y es igual de barato.

**Hipótesis principal (sin confirmar)**: el keepalive de 60 s deja la sesión vieja viva 90 s, más que el ciclo de ~63 s del nodo, así que cada reconexión fuerza un takeover por client-ID duplicado — mecanismo que **predice la alternancia observada**, cosa que la radiofrecuencia no puede. El análisis completo, el experimento de una línea (keepalive corto en el ciclo normal, largo sólo en service mode), los comandos de verificación y las vías alternativas están en `../STATUS.md` → "Pérdida de telemetría".

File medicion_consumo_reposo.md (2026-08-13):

# Medición del consumo de reposo — procedimiento de banco

**Estado: pendiente de ejecución.** Preparado el 2026-08-11, para hacer con multímetro de mano en banco.

Es la medición de mayor valor pendiente del proyecto: decide si tiene sentido optimizar la ventana activa o el reposo. Ver `componentes_y_conexiones.md` → "El reposo pesa más que la ventana activa" para el contexto que la motiva, y `../STATUS.md` → "Power management".

---

## 1. Qué se busca y qué número lo decide

El presupuesto energético actual está estimado indirectamente, desde la caída de tensión de la batería durante la noche (5 noches, mediana 5,10 mA de consumo medio total):

| | mA medios | mAh/día | cómo se sabe |
|---|---|---|---|
| Ventana activa | 1,86 | 44,7 | **medido** — 51,2 mA × 3,64% de ciclo de trabajo |
| Reposo | ~3,2 | 77,7 | **por diferencia, nunca medido directo** |
| **Total** | **5,10** | **122,4** | estimado de la caída nocturna |

El 63% del presupuesto está sin explicar, y **no hay cambio de firmware que lo resuelva**: el INA219 se apaga al dormir, y aunque no se apagara, no hay nadie despierto para leerlo.

### La predicción falsable

Si la estimación indirecta es correcta, **el nodo dormido tiene que consumir ~3,2 mA de la batería**. Ese es el número a confirmar o desmentir en la medición M2. Si sale muy distinto, lo que está mal es el método de la caída nocturna (la conversión volts→mAh usa la curva de SoC del backend, que es un indicador y no una contabilidad).

### Sospechosos, en orden

1. **Reposo del step-up boost** — el principal. Tiene que estar siempre encendido porque alimenta al ESP32 que despierta, y los módulos de esta clase se citan en 0,5–2 mA, empeorando a carga liviana.
2. **El regulador propio de la SuperMini** más el deep sleep del ESP32-C3.
3. **El CN3791 de noche** — nunca cuantificado. Sus dos LEDs ya están descartados: sólo encienden cuando el panel entrega (confirmado 2026-08-09).
4. Los dos INA219 en power-down son ~12 µA entre ambos y no explican nada. Los LEDs de los módulos están todos desoldados.

---

## 2. La topología, y los dos regalos del PCB

```
Panel ──[INA219 solar 0x41]──▶ CN3791 ──┬──▶ batería LiPo 1500 mAh (JST PH 1.25)
                                        │
                                        └──[INA219 sys 0x40]──▶ boost 5V ──▶ ESP32-C3
                                                                              │
                                                                    LDO onboard ──▶ bus 3V3
                                                                                     ├─ 2× INA219 Vcc
                                                                                     └─ pull-ups I2C
```

El CN3791 no tiene salida de carga separada, así que **batería, cargador y carga comparten un solo nodo**. Eso define los dos puntos de inserción útiles:

- **En la línea de batería** → consumo *total* (incluye al CN3791).
- **En la entrada del boost** (o del INA219 de sistema) → sólo la rama de carga, *excluye* al CN3791.

Dos cosas del armado hacen esto mucho más fácil de lo que parecía:

- **La SuperMini está sobre headers hembra** (`componentes_y_conexiones.md`, zona ESP32-C3, 8× hembra por lado): se puede **desenchufar sin desoldar**. Con el ESP32 afuera no hay ráfagas de WiFi, y la corriente es DC estable — trivial de medir.
- **El power-down del INA219 no abre el shunt**, así que el camino de corriente es idéntico dormido y despierto. Nada que compensar.

---

## 3. El problema del burden voltage, y cómo esquivarlo

Un multímetro de mano en rango de mA mete un shunt de ~1–10 Ω en serie:

| estado | corriente | caída con 10 Ω | consecuencia |
|---|---|---|---|
| dormido | ~3 mA | ~30 mV | ✅ irrelevante |
| despierto | 51 mA | ~510 mV | ⚠️ tolerable |
| ráfaga de asociación WiFi | cientos de mA | volts | ❌ **brownout / reset** |

Un nodo que se resetea en loop no está en deep sleep, así que la lectura no valdría nada.

**Solución: un puente en paralelo con el multímetro.** Un cable con pinzas cocodrilo cruzado sobre las dos puntas.

- **Puente cerrado** → la corriente pasa por el cable, el multímetro no ve nada, el nodo funciona sin burden.
- **Puente abierto** → toda la corriente pasa por el multímetro y se lee.

Se abre sólo durante la ventana de sueño y se cierra antes del próximo despertar.

### Cómo saber cuándo está dormido

**El dashboard tiene la cuenta regresiva al próximo publish** y es exacta desde el backend `1.3.2` (el nodo reporta `next_s` = 60 y el backend calcula 64 s con el overhead de despertar). El ciclo es ~2,3 s despierto de cada ~64: hay casi un minuto de ventana tranquila.

> Mantené el nodo publicando durante la prueba — el dashboard es el reloj. Si le sacás el WiFi, `connectWiFi()` agota reintentos y se queda **hasta 45 s despierto** tirando 51 mA, que es lo contrario de lo que se quiere.

Protocolo: esperá a ver un publish nuevo → contá ~10 s → abrí el puente → leé → cerrá el puente antes de que la cuenta llegue a cero.

---

## 4. Las tres mediciones, de la más fácil a la más difícil

**El doc original proponía empezar por el total y después descomponer. Conviene al revés**: las mediciones sin ráfagas son las que aíslan al sospechoso principal, y no necesitan puente ni cronometrar nada.

| | punto de inserción | ESP32 | qué mide | ¿ráfagas? |
|---|---|---|---|---|
| **M1** | línea de batería | **fuera del zócalo** | CN3791 + boost en vacío | no |
| **M3** | entrada del boost | **fuera del zócalo** | boost en vacío solo | no |
| **M2** | línea de batería | dentro, nodo dormido | **reposo total** | sí → puente |

Las restas:

```
M1 − M3  =  CN3791 de noche
M2 − M1  =  rama del ESP32 (deep sleep + LDO + INA219 + pull-ups)
M2       =  el número que valida (o rompe) la estimación de 3,2 mA
```

**M3 es opcional**: depende de si la entrada del boost es accesible sin desoldar. Si el módulo está soldado a la placa, saltealo — M1 y M2 solas ya contestan la pregunta principal.

### Un factor de conversión que hay que aplicar

Cualquier corriente medida **del lado de 5 V** (después del boost) se refiere a la batería multiplicando por ~1,5:

```
I_batería ≈ (5 V × I_5V) / (3,9 V × η)     con η ≈ 0,85  →  ~1,5×
```

Las tres mediciones de arriba son todas del lado de la batería, así que no hace falta — pero si alguna vez medís entre el boost y la SuperMini, acordate.

---

## 5. Antes de tocar nada

### Seguridad

> ⚠️ **El error clásico de multímetro, y con una LiPo es serio:** dejar las puntas en los jacks de corriente (A / mA) y usarlo como voltímetro. Eso pone un shunt de ~1 Ω directo sobre la batería — cortocircuito franco. Quema el fusible en el mejor caso.
>
> **Regla: después de cada medición de corriente, devolvé la punta roja al jack de volts.**

- Desconectá el **panel** (JST solar) antes de empezar. En banco no hace falta, pero si por lo que sea hay luz sobre el panel, la corriente de carga se suma y la lectura pasa a ser *carga − consumo*, que no es lo que se busca.
- Conectá y desconectá siempre con la batería fuera del circuito primero. El JST PH 1.25 es chico y dos pines juntos sobre una LiPo de 1500 mAh no perdonan.
- No dejes el nodo desarmado con la batería conectada más de lo necesario.

### Qué tener a mano

- Multímetro con rango de mA (resolución de 0,01 mA o mejor).
- **Un cable con pinzas cocodrilo** para el puente. Es lo único no obvio de la lista y es lo que hace viable M2.
- Algo para intercalar en la línea de batería sin forzar el JST: un pigtail JST PH 1.25 macho-hembra cortado es lo ideal. Si no hay, ver la nota de abajo.
- El dashboard abierto, para la cuenta regresiva.

> **Punto a confirmar visualmente al abrir la caja**, que no pude resolver desde la documentación: cómo intercalar en la línea de batería sin pigtail. Los candidatos son el JST de la batería, los pines de entrada del CN3791, o los pads del PCB. Si ninguno es cómodo, decímelo con una foto y lo replanteamos — no fuerces el conector.

### Que el hueco en los datos sea esperado, no un susto

Mientras el nodo esté en el banco va a seguir publicando con el panel desconectado y los sensores adentro de la casa: `solar_v` ≈ 0, `photo_kohm` probablemente en el centinela 9999, temperatura y humedad de interior. **Es esperado.** El backend puede marcar estado energético raro y el dashboard mostrar cosas sin sentido meteorológico — no es una falla. Anotá la hora de inicio y fin para poder identificar la ventana después en InfluxDB.

Con `LIVE_AUTO_ENABLED=false` (que es como está) el backend no va a intentar armar live mode por su cuenta.

---

## 6. Procedimiento

### M1 — CN3791 + boost en vacío *(empezar acá)*

1. Panel desconectado. Batería desconectada.
2. **Sacá la SuperMini del zócalo.** Guardala aparte.
3. Multímetro en rango de mA, en serie en la línea de batería.
4. Reconectá la batería (a través del multímetro).
5. Esperá ~10 s a que se estabilice y anotá. **No hay ráfagas: la lectura tiene que ser un valor quieto.**

Si oscila, algo más está conectado de lo que creés — pará y revisá antes de seguir.

### M3 — boost en vacío solo *(opcional, si la entrada es accesible)*

Igual que M1, pero con el multímetro en la entrada del boost en vez de en la línea de batería. La diferencia contra M1 es lo que consume el CN3791.

### M2 — reposo total *(la que necesita el puente)*

1. Batería desconectada. **Volvé a enchufar la SuperMini** en su zócalo, con cuidado de la orientación.
2. Multímetro en serie en la línea de batería, **con el puente de cocodrilos cerrado sobre sus puntas**.
3. Reconectá la batería. El nodo arranca; el puente lo protege del burden.
4. Confirmá en el dashboard que está publicando normal.
5. Esperá a ver un publish nuevo, contá ~10 s, **abrí el puente**.
6. Leé. Debería estabilizarse en pocos segundos.
7. **Cerrá el puente** antes de que la cuenta regresiva llegue a cero.
8. Repetí 3 veces y quedate con la mediana — es gratis y descarta una lectura tomada durante un transitorio.

---

## 7. Cómo interpretar el resultado

### Primero: ¿se sostiene la estimación indirecta?

**M2 ≈ 3,2 mA** → la estimación de la caída nocturna era buena, y el presupuesto de 122,4 mAh/día vale. Seguí con la descomposición.

**M2 muy distinto** (digamos fuera de 1,5–6 mA) → lo que hay que revisar es el método indirecto, no el hardware. La conversión volts→mAh depende de la curva de SoC, y la temperatura baja de noche sube la resistencia interna, así que parte de la caída podía ser térmica y no consumo.

### Después: ¿quién se lo lleva?

| resultado | lectura | qué sigue |
|---|---|---|
| **M1 ≈ M2** (la rama del ESP32 es chica) | El ESP32 duerme bien; se lo lleva el boost y/o el CN3791 | **Es el caso esperado.** La palanca es el boost — ver abajo |
| **M1 pequeño, M2 − M1 grande** | El boost está bien y el problema es el ESP32 o su LDO | Sospechar el LDO de la SuperMini; medir la rama de 5 V por separado |
| **M1 − M3 grande** | El CN3791 drena de noche más de lo que se suponía | Novedad — no estaba en la lista de sospechosos con peso |
| **Todo chico, M2 chico** | El reposo no es el problema | Vuelve a valer la pena optimizar la ventana activa, y la estimación nocturna estaba mal |

### Si el boost resulta ser el culpable

**No hay que decidirlo ahora, pero conviene saber que la palanca existe**: el boost está para llevar 3,7–4,2 V de la LiPo a 5 V, que la SuperMini vuelve a bajar a 3,3 V con su LDO. Son dos conversiones para terminar por debajo de donde arrancó. Si el reposo del boost resulta ser 2 de los 3,2 mA, la pregunta que se abre es si el boost tiene que existir.

**No investigué esa alternativa todavía** — depende de si la SuperMini expone 3V3 como entrada, del rango de dropout, y del comportamiento con la batería casi descargada. Es trabajo para cuando haya número, y toca hardware, así que va con su propia investigación antes de recomendar nada.

---

## 8. Dónde anotar el resultado

| medición | valor | fecha |
|---|---|---|
| M1 — CN3791 + boost en vacío | | |
| M3 — boost en vacío solo *(opcional)* | | |
| M2 — reposo total, nodo dormido | | |

Cuando estén, actualizar:

- `componentes_y_conexiones.md` → "El reposo pesa más que la ventana activa" (hoy dice "estimado, sin medir")
- `aprendizajes_y_roadmap.md` → el ítem "Medir el consumo de reposo con multímetro"
- `../STATUS.md` → sección de power management

---

## 9. Lo que sigue después

Con el número en mano se retoma **el promediado por hardware del INA219**, que quedó planificado en dos pasos (ver `aprendizajes_y_roadmap.md` → "Medir la energía de la ventana activa"):

- **Paso 1, sólo firmware**: despertar el INA219 al inicio de `setup()` y escribir el registro de configuración `0x00` después de cada `begin()`, para que `system_mA`/`system_v`/`system_mW` pasen a ser promedios de hardware en vez de un snapshot de 532 µs. Sin cambios de payload, backend ni N8N.
- **Paso 2**: integrar la ventana completa (`active_mAs` + `awake_ms`), que toca los cuatro eslabones de la cadena.

Cuatro hallazgos de la revisión de código del 2026-08-11 que corrigen premisas del diseño en papel están anotados en `aprendizajes_y_roadmap.md`, en esa misma sección.

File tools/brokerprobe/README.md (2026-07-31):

# brokerprobe — medir la pérdida de telemetría desde la LAN

Herramientas de la investigación del 2026-07-29/31, que terminó en el fix de
`WIFI_FORCE_11B` (ver [`../../../STATUS.md`](../../../STATUS.md)).

Se versionan porque **cambiaron el costo de medir**: antes, saber cuánta
telemetría se perdía costaba una captura de logs en el nodo, una sesión de
service mode y una transferencia paginada — o sea una noche y una operación cara.
Con esto son 35 minutos desde la LAN, sin tocar el nodo. Si el enlace vuelve a
degradarse, esto es lo primero que se quiere tener a mano.

## `brokerprobe` (Go)

```
go build -o brokerprobe.exe .
./brokerprobe.exe -dur 35m -out captura.ndjson
```

Se suscribe al broker con un client-ID propio y registra cada telemetría con su
payload completo. Además lee los contadores `$SYS/broker/#` que publica Mosquitto,
y ahí está lo que no se puede obtener de otra forma:

`$SYS/broker/publish/messages/received` y `.../bytes/received` se incrementan en
`handle__publish`, **antes de rutear**, así que dicen si el broker *ingresó* el
mensaje con independencia de a quién se lo entregue. Un tercer suscriptor no
puede contestar eso: si el broker descarta en el ingreso, todos los suscriptores
pierden igual.

Mosquitto publica cada valor de `$SYS` **sólo cuando cambia**, así que la
secuencia de mensajes es la secuencia de transiciones con su timestamp.

## Análisis

| script | qué hace |
|---|---|
| `analyze.py` | tasa de pérdida por huecos de `boot_count`, y la aritmética de bytes que localiza en qué punto del ciclo se cortó |
| `linkstate.py` | lee los campos `pv_*` (si el firmware los publica) y separa cómo cerraron los ciclos perdidos de los que llegaron |
| `crossref.py` | cruza una captura del sniffer 802.11 con las llegadas al broker: RSSI y reintentos de los ciclos perdidos contra los que llegaron |

## `pingstorm.ps1`

Sondeo ICMP a intervalo corto. El nodo contesta ping durante su ventana despierta,
así que la duración de esa ventana acota **cuándo** dejó de estar en la red dentro
del ciclo. Alterna tamaños de payload para separar fallas dependientes del tamaño
de frame.

Usa `System.Net.NetworkInformation.Ping` y no `ping.exe` porque éste tiene el
intervalo fijo en 1 s y a esa resolución la ventana entera son 2 muestras.

## `serialcap.ps1`

Captura el serial del sniffer a un archivo, acotada en tiempo. **No toca DTR ni
RTS**: en el USB-Serial-JTAG del ESP32-S3 esos pines gobiernan IO0 y EN con lógica
propia del periférico, y cualquier toque deja la placa en modo descarga esperando
un flasheo que nunca llega. Costó un rato descubrirlo.

## Trampas que ya se pagaron

- **Las ventanas tomadas en horarios distintos no son comparables.** La tasa de
  reintentos se movió de 29% a 54% *dentro de una misma hora*. Para un A/B que
  importe, alternar los brazos en la misma franja o aceptar que sólo se detectan
  efectos grandes.
- **La posición del sniffer es parte de su calibración.** 23 cm de altura (casi
  dos longitudes de onda a 2,4 GHz) lo llevaron de oír al nodo a no oírlo en
  absoluto, e invalidaron una conclusión que se había dado por buena.
- **PowerShell resuelve las rutas relativas contra el directorio del proceso**,
  no contra `Set-Location`. Pasar rutas absolutas a `-Out` o el archivo aparece
  en cualquier lado.

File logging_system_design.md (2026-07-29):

# Sistema de logs del nodo — diseño

> Diseñado el 2026-07-27/28 (Mau + Claude). Los contratos de este documento cruzan los tres repos: firmware (`weather-station-station-iot`), backend Go (`weather-station-backend-service`) y dashboard React (`weather-station-frontend-dashboard`). Antes de tocar cualquiera de los tres, leer al menos las secciones "Formato de entry", "Diccionario" y "Protocolo de recuperación".

## Qué problema resuelve

Hoy el nodo en campo **no tiene observabilidad**. `LOG_V` y `LOG_E` (`src/config.h`) son `Serial.printf` y con `LOG_LEVEL=0` compilan a no-op, así que la única forma de ver algo es abrir la caja estanca y enchufar USB. La alternativa —flashear un build de debug— cuesta el `delay(2000)` por wake y sigue sin poder leerse a distancia.

El disparador concreto: **~17% de los ciclos no publican telemetría** y no hay forma de saber si falla WiFi o MQTT. `boot_count` incrementa antes de la red, así que se sabe que el nodo despertó, y nada más.

### Qué NO es

**No es `LOG_LEVEL`.** Aquel es compile-time y sale por Serial; éste se activa en runtime y sale por MQTT. Conviven, y lo importante es que **este sistema va compilado en el build de producción**. Si quedara detrás de `LOG_LEVEL>0`, para debuggear habría que flashear un build de debug — exactamente lo que el sistema existe para evitar.

## Modelo mental

Como el logging de un router comercial: acumula internamente hasta un límite, se pisa lo viejo, y se puede consultar. La diferencia es que un router está enchufado y este nodo cuida cada mA.

De ahí la decisión de fondo: **el logging se activa a demanda, no corre siempre**. El operador sabe cuándo lo necesita, igual que sabe cuándo conviene flashear según el SoC de la batería.

Flujo completo:

```
necesito debuggear algo
   → activo logging (comando liviano, ciclo normal, el nodo sigue durmiendo)
   → dejo correr N horas
   → entro a service mode y traigo los logs (paginado)
   → el backend confirma que recibió todo
   → el nodo borra y se desactiva solo
   → si no capturé lo que buscaba, repito
```

## Restricciones que dan forma al diseño

| Restricción | Consecuencia |
|---|---|
| El deep sleep borra la RAM normal | El buffer vive en **RTC memory** |
| `RTC_DATA_ATTR` sólo sobrevive al deep sleep; un panic, un watchdog, una brownout o un reboot lo recargan desde flash | El estado va en **`RTC_NOINIT_ATTR`**, validado con una palabra mágica |
| El ESP32-C3 tiene **8176 B de RTC memory** y nada más (`memory.ld:59`, `0x2000 - 0x10`; en el C3 `rtc_data_seg`/`rtc_slow_seg`/`rtc_iram_seg` son la misma región) | La captura se mide en **horas, no en días** |
| No hay RTC de hardware ni NTP, y `millis()` se reinicia en cada ciclo | No se puede timestampear en el nodo; lo reconstruye el backend |
| El topic `cmd` es **retenido y de slot único** | El comando se consume y se limpia en el acto; el estado vive en RTC |
| Buffer MQTT de 768 B | El dump va **paginado** |
| El nodo está despierto ~3,3 s por ciclo y no escucha | El dump ocurre en **service mode** |

## Formato de entry — 8 bytes

```c
struct LogEntry {
    uint16_t boot;   // boot_count truncado a 16 bits — 45 días a 60 s
    uint16_t ms;     // ms desde el arranque de ese ciclo (un ciclo fallido son ~45 s, entra)
    uint8_t  code;   // qué pasó — ver diccionario
    uint8_t  a;      // argumento chico: nro de intento, estado MQTT, índice de sensor
    int16_t  b;      // argumento grande: RSSI, bytes, duración en ms
};
```

Ocho bytes, alineado, sin punteros ni strings. Escribir una entry es un `memcpy` de 8 B: **la captura es energéticamente gratis**. Esto importa más de lo que parece — significa que el modo logging no mueve la aguja del consumo mientras corre, y que el único costo real está en el dump, que es operador-iniciado.

> **Corrección respecto de la conversación de diseño**: se había propuesto una guarda que desactivara el logging con batería baja. **Se descarta**: partía de suponer que capturar costaba energía, y no cuesta. La única operación cara es el dump, que ya está cubierta por el semáforo de batería que existe en la vista de service mode.

## Ring en RTC memory

```c
RTC_NOINIT_ATTR LogEntry rtc_logRing[LOG_RING_ENTRIES];
RTC_NOINIT_ATTR uint16_t rtc_logHead;      // próxima posición a escribir
RTC_NOINIT_ATTR uint16_t rtc_logCount;     // entries válidas (satura en la capacidad)
RTC_NOINIT_ATTR uint32_t rtc_logDropped;   // entries pisadas al dar la vuelta
RTC_NOINIT_ATTR uint8_t  rtc_logLevel;     // 0 = off
RTC_NOINIT_ATTR uint32_t rtc_logMagic;     // validez + geometría
```

### `NOINIT` y no `DATA` — corregido en la revisión previa al flasheo del 1.3.0

Según `esp_attr.h` del core, `RTC_DATA_ATTR` conserva el valor *"during a deep sleep / wake cycle"* mientras que `RTC_NOINIT_ATTR` lo conserva *"after restart or during a deep sleep / wake cycle"*. La primera versión usaba `RTC_DATA_ATTR`, y eso significaba que **un panic, un watchdog, una brownout o un comando `reboot` borraban la captura entera y dejaban el nivel en 0**.

Lo grave no era perder los datos sino que era **silencioso**: la captura se desarmaba sola y la UI mostraba "Captura detenida" sin explicación. Y había una ironía — el `esp_reset_reason()` del evento de boot existe justamente para distinguir brownout de panic, pero esa entry nunca llegaba a escribirse, porque cuando `setup()` la intentaba el nivel ya era 0.

El precio de `.rtc_noinit` es que arranca con basura en un power-on. Por eso `logging_begin()` valida, antes del primer `logging_write()`, cuatro cosas:

| Chequeo | Qué atrapa |
|---|---|
| Palabra mágica | Basura de un power-on |
| Geometría (`LOG_RING_ENTRIES`, `sizeof(LogEntry)`) | Un firmware futuro que cambie el tamaño del ring o de la entry |
| **Huella del diccionario** (FNV-1a sobre nombres, plantillas y niveles) | Un firmware que agregue o reordene códigos |
| Invariantes de `head`/`count`/capacidad | Corrupción sutil que pasó los anteriores |

La huella del diccionario merece explicación porque cubre el único caso que los otros tres **no** ven, y es el más probable de todos: ahora que el ring sobrevive a un reflash, un firmware que agregue un código de log heredaría entries viejas con la misma geometría, y el backend las decodificaría con el diccionario nuevo. Saldrían **silenciosamente mal etiquetadas**, que es peor que perderlas. Con la huella, un cambio de diccionario descarta la captura y se arranca limpio. Cambiar entre los builds `production` y `development` no la altera —el diccionario es el mismo— así que ahí la captura sí sobrevive, que es lo correcto.

Los invariantes son defensa en profundidad: cuestan tres comparaciones y convierten una corrupción sutil en un reinicio limpio en vez de en un índice fuera de rango, que en RTC memory pisaría las variables de al lado.

Efecto secundario: `.rtc_noinit` es `NOBITS`, así que los 6 KB del ring **dejaron de ocupar lugar en la imagen de flash**.

**Dos cosas que esto NO cubre**, y conviene tenerlas escritas:

- **Un cambio de layout de ese bloque de variables.** Si se agregan o reordenan las `RTC_NOINIT_ATTR` de `logging.cpp`, la mágica se lee de otra dirección y podría coincidir con datos viejos. Hay que **bumpear `LOG_STATE_MAGIC` a mano**.
- **La retención en una brownout es best-effort.** Si la tensión cae por debajo de lo que el dominio RTC necesita para retener, el contenido se pierde igual — y la pérdida puede ser parcial: la mágica sobrevive mientras el ring se corrompe. En ese caso las entries salen con códigos y argumentos sin sentido; el backend las muestra como código desconocido cuando el número no existe, pero un byte corrupto que caiga dentro del rango válido se va a ver como un evento real con argumentos absurdos. Es visible a ojo, no silencioso, y no justifica un CRC que habría que mantener en cada escritura.

`LOG_RING_ENTRIES` es **compile-time** — la RTC memory no se puede redimensionar en runtime. Default propuesto: **768 entries = 6 KB**, dejando margen sobre los 8176 B para el sistema y las otras variables RTC. Si se pasa, el linker falla con `region rtc_iram_seg overflowed`, así que el error se detecta al compilar y no en campo.

**Consecuencia para la UI**: el parámetro `entries` del comando de activación sólo puede **achicar** el ring, nunca agrandarlo. Sirve para acortar dumps cuando alcanza con la historia reciente. El parámetro que de verdad mueve la ventana de captura es el **nivel**, no el tamaño.

`rtc_logDropped` no es cosmético: sin él no se puede distinguir una captura completa de una truncada, o sea no se sabe si la ventana llegó a cubrir el evento que se buscaba.

## Niveles y ventana de captura

| Nivel | Qué registra | Entries/ciclo | Captura con 768 entries |
|---|---|---|---|
| 0 | Nada (off) | 0 | — |
| 1 | Sólo anomalías | ~0,7 | **~18 h** |
| 2 | Resumen por ciclo + anomalías | ~1,7 | **~7,5 h** |
| 3 | Verboso (cada intento) | ~5 | **~2,5 h** |

Con ciclos de 60 s. El nivel 2 es el default razonable: a 17% de fallos son ~10 ciclos fallidos por hora, así que en 7 h se capturan ~70 — muchísimo más de lo necesario para separar WiFi de MQTT.

La UI debería mostrar la ventana estimada en vivo al mover el selector de nivel.

## Diccionario — el nodo es la autoridad

El backend no sabe nada del dominio: recibe `(code, a, b)` y una plantilla, y sustituye. Un X-macro genera el enum y la tabla desde **una sola definición**, así que código y texto no pueden desincronizarse ni siquiera dentro del firmware.

```c
#define LOG_CODES(X) \
    X(BOOT,        "boot #%a — reset=%b") \
    X(WIFI_TRY,    "wifi intento %a (%b = canal cacheado, 0 = scan)") \
    X(WIFI_OK,     "wifi ok — intento %a, rssi %b dBm") \
    X(WIFI_FAIL,   "wifi timeout — intento %a, status %b") \
    X(MQTT_OK,     "mqtt conectado en %b ms") \
    X(MQTT_FAIL,   "mqtt rechazado — state %b") \
    X(CMD_RX,      "comando retenido recibido — tipo %a") \
    X(PUBLISH_OK,  "telemetría publicada — %b B") \
    X(PUBLISH_FAIL,"publish falló — %b B, ¿buffer corto?") \
    X(SLEEP,       "durmiendo — %b ms despierto")
```

Las plantillas llevan `%a` y `%b`, así que el nodo define también **cómo interpretar los argumentos**, no sólo los nombres. Eso es lo que hace real el "el nodo manda".

**Caché por versión**: el diccionario se pide sólo cuando el backend ve un `firmware` que no conoce — y ese campo ya viaja en todos los payloads. En régimen no cuesta nada y se auto-repara al flashear.

**El export a disco tiene que llevar el diccionario adentro.** Si no, un archivo de hace seis meses queda ilegible cuando el firmware avanzó, que es el mismo problema de desincronización corrido en el tiempo.

### `esp_reset_reason()` en el evento BOOT

Es gratis y distingue brownout de panic de wake normal. Dada la situación solar/batería, la brownout es una hipótesis viva que hoy no se puede ni confirmar ni descartar.

## Reconstrucción de timestamps

El nodo no puede timestampear. Cada entry lleva `boot` + `ms`, y el **backend** reconstruye la hora de pared:

1. Los boots que **sí** publicaron telemetría dan anclas: el backend conoce la hora de recepción y el `boot_count` del payload.
2. Los huecos se interpolan asumiendo el `SLEEP_INTERVAL_SEC` nominal.
3. Dentro de un ciclo, `ms` da el orden y la duración exactos.

**Precisión honesta**: el timer de deep sleep corre sobre un oscilador RC interno con ±5%, así que interpolar 7 ciclos perdidos acumula ~±21 s de error. Para correlacionar logs sobra, y cada telemetría exitosa vuelve a anclar. Un RTC de hardware eliminaría todo esto — ver `aprendizajes_y_roadmap.md` → "Evolución candidata: nodo offline".

### La frontera de reinicio

Ahora que el ring sobrevive a un reinicio pero `rtc_bootCount` no —ese contador sigue en `.rtc.data`, que se recarga desde flash en cualquier arranque que no sea wake de deep sleep— **una misma captura puede contener ciclos numerados por dos series distintas del contador**.

El evento de boot lleva `esp_reset_reason()`, así que la frontera es detectable: cualquier valor distinto de 8 (`ESP_RST_DEEPSLEEP`) marca dónde el contador volvió a empezar. El backend busca la última de esas entries y ancla sólo de ahí en adelante; lo anterior se entrega **con su número de ciclo crudo y sin hora**, más una nota que lo explica. El orden entre esos eventos sigue siendo correcto, porque el ring es cronológico.

Sin esto, las entries previas al reinicio se fecharían contra un ancla que no les corresponde y darían horas inventadas — peor que no tener hora.

### `ms` satura a los 65 s

El campo son 16 bits, así que topea en 65535 ms. Un ciclo normal no llega ni en el peor caso teórico (los tres reintentos de WiFi son 45 s, más MQTT y sensores da ~55 s), y en la práctica queda muy lejos: **medido en campo el 2026-07-28, un ciclo sano dura 3,3 s y uno fallido 5,7–6,2 s**. Pero **una sesión de service mode dura minutos**: todas las entries posteriores a los 65 s colapsan al mismo valor. En la práctica afecta a una sola entry por sesión, la de salida — la de entrada se escribe enseguida y es exacta, y la duración real de la sesión viaja igual en su argumento `b`. Se acepta: dar más rango costaría la resolución de milisegundos dentro del ciclo, que es justo lo que hace útil el diagnóstico de conexión.

## Comandos

### Activación — `log_on`

```json
{"cmd":"log_on", "level":2, "entries":768}
```

Se procesa en `handleCommand()` como un `CommandType::LOG` nuevo. **No entra en service mode**: setea el estado en RTC, limpia el retenido en el acto, y sigue el ciclo normal (telemetría + sleep). El logging corre durante los ciclos normales de 60 s, que es todo el punto.

> Limpiar el retenido no es opcional. Es *la* clase de bug recurrente de este firmware: el loop de `reboot` y los stubs `CONFIG`/`CALIBRATE` fueron exactamente esto. Un comando que se ejecuta y no se borra se vuelve a leer en cada wake, para siempre — y encima bloquea el slot para cualquier otro comando.

`{"cmd":"log_on","level":0}` desactiva sin dumpear.

### Visibilidad

Mientras el logging está activo, la telemetría incluye `log_active` y `log_count`. Se omiten cuando está apagado, igual que los campos condicionales que ya existen — costo cero en operación normal. Sin esto es fácil activar el logging y olvidarse por meses.

No hay auto-expiración por tiempo: como capturar es gratis, la hygiene correcta es **visibilidad**, no un timer.

## Protocolo de recuperación

Topics nuevos, **sin retain**, para no pelear contra la semántica del slot único de `cmd`:

| Topic | Sentido | Payload |
|---|---|---|
| `station/01/log/req` | backend → nodo | `{"page":3}` · `{"dict":true}` · `{"clear":true,"keep":false}` |
| `station/01/log/data` | nodo → backend | `{"page":3,"pages":13,"dropped":0,"b64":"..."}` |

**Pull, no push.** El backend pide página por página. Si se pierde un chunk, volver a pedirlo es el mismo mensaje de siempre — no hace falta lógica de retransmisión. Y el ack cae solo: el backend tiene todas las páginas → recién ahí manda `clear`.

**El dump ocurre en service mode**, donde el nodo ya está despierto y suscripto. La UI puede encadenar todo detrás de un botón: entrar a service mode → pedir diccionario si hace falta → paginar → verificar → clear → salir.

**Codificación**: base64 del slice binario crudo del ring. JSON con arrays de números infla ~3×; base64 infla 1,33× y el struct es de tamaño fijo, así que cortar en páginas es aritmética simple.

Presupuesto real, contado byte por byte: el buffer MQTT son 768 B, menos header (5), largo (2) y el topic `station/01/log/data` (19) → **742 B útiles**. El wrapper JSON en su peor caso mide 77 B (`dropped` es uint32 y puede llegar a 10 dígitos), así que quedan 665 B para el base64 = 498 B binarios = 62 entries.

Se usan **55 entries por página** (440 B → 588 B de base64 → 665 B de payload, 77 B de margen), o sea **14 páginas** para un ring lleno de 768. Con 60 el margen bajaba a 25 B, y pasarse no falla ruidosamente: `serializeJson` trunca en silencio y recién después `publish()` rechaza el mensaje, dejando esa página irrecuperable por más que el backend la reintente.

### Borrado en dos fases

El nodo **no borra hasta que el backend confirma** que recibió todas las páginas. Después de horas de captura, una transferencia incompleta o una pestaña cerrada a mitad de camino no puede costar la sesión entera.

`{"clear":true,"keep":true}` trae un snapshot **sin** desactivar el logging, para investigaciones largas. El default sigue siendo desactivar y limpiar.

## Reparto de trabajo por repo

**Firmware** (`weather-station-station-iot`)
- `src/logging.{h,cpp}` nuevo: X-macro de códigos, ring en RTC, `log_write(code, a, b)`, serialización a base64 por página.
- `src/command.{h,cpp}`: `CommandType::LOG` + parseo de `level`/`entries` con clamp (mismo criterio que `timeout_min`, ver el bug de overflow ya corregido).
- `src/main.cpp`: instrumentar el camino de conexión, despachar `LOG`, agregar los campos condicionales a la telemetría.
- `src/service_mode.cpp`: atender `log/req` durante la sesión.

**Backend** (`weather-station-backend-service`)
- Suscripción a `log/data`, reensamblado por páginas, reintento de faltantes, emisión del `clear` sólo con la captura completa.
- Caché del diccionario por versión de firmware, **persistente** (si vive sólo en memoria, un reinicio del backend deja ilegible un export viejo).
- Reconstrucción de timestamps por interpolación anclada en telemetría.
- Endpoints bajo `/api/v1/logs/`, en línea con los `/api/v1/service/` que ya existen.

**Frontend** (`weather-station-frontend-dashboard`)
- Panel de logging en la vista de service mode: activar/desactivar, selector de nivel con ventana estimada, estado de captura.
- Visor con filtro por código, y export self-contained (logs + diccionario + anclas de tiempo).
- Aviso explícito de las dos cosas que pasan al traer los logs: se desactiva y se borra del nodo.

## Pendientes de decisión

- ~~**Umbral exacto de `LOG_RING_ENTRIES`**~~ — **resuelto: 768 entries (6144 B)**. Medido sobre el ELF de `production` con 768: las secciones RTC terminan en `0x50001850`, o sea **6224 B usados de los 8176 disponibles**, con **1952 B libres**. Técnicamente entrarían ~1000 entries, pero se deja el margen: los contadores de pulsos del anemómetro y el pluviómetro, que son un TODO conocido en `config.h`, también van a vivir en RTC memory.
- **Formato del export** — NDJSON ya se usa para el visor de payloads de service mode; conviene reusarlo por consistencia, pero necesita un header con el diccionario.
- **Tier de flash (SPIFFS)** — hay 320 KB declarados y sin usar en `partitions_ota.csv`. Daría días en vez de horas y sobreviviría a la pérdida total de energía, a costa de un mount por wake y riesgo de corrupción por brownout. **Decidido no hacerlo por ahora**: RTC sola resuelve el caso de uso concreto. Se reconsidera si aparece una investigación que necesite días.

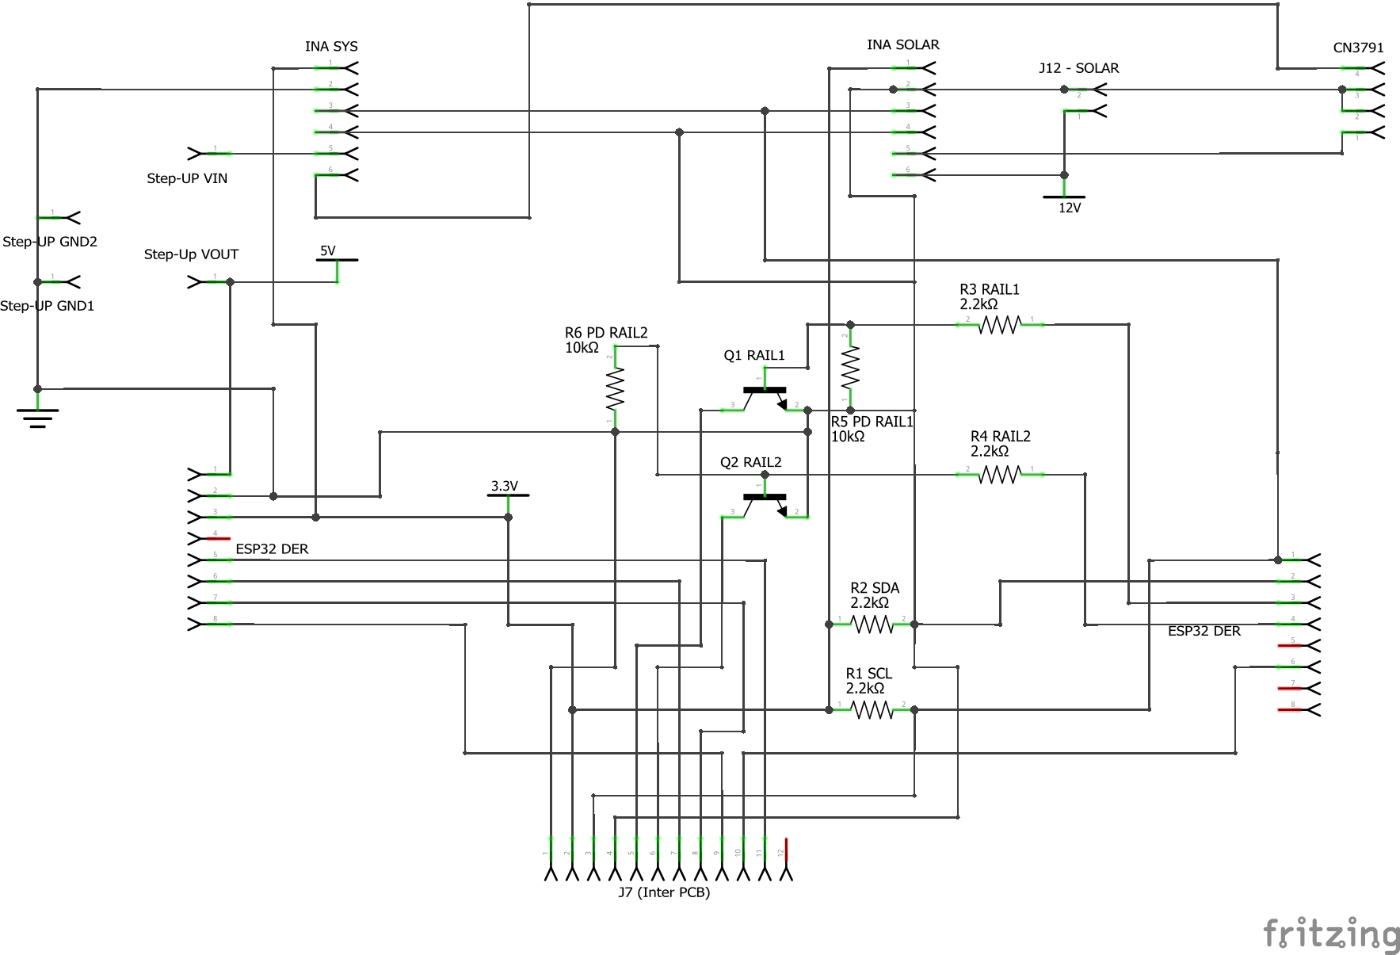
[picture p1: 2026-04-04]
Estación Meteorológica - IoT_v1.2_esquemático.png

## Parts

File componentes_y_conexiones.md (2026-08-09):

\# Estación Meteorológica Solar — Componentes y Conexiones

\*\*Embalse, Córdoba, Argentina · Rev 2.0\*\*

&#x20;

\---

&#x20;

\## Estado actual en campo (actualizado 2026-07-31)

&#x20;

\*\*Hardware en campo: PCB v2 (main + aux), con doble capa de barniz aislante aplicada.\*\* El prototipo de dos perfboards con cold solder joints ya no está en servicio, y el issue de I2C intermitente quedó cerrado — ver `../STATUS.md`.

&#x20;

\*\*Firmware en campo: `1.15.0`\*\* (el `1.16.0` está commiteado, sin flashear). Historial reciente: `1.1.0` (DHT22) → `1.2.0` (service mode + fix del loop de reboot) → `1.3.0`/`1.3.1` (sistema de logs) → `1.4.0` (INA219 en power-down) → `1.5.0` (warmup del DHT22 en paralelo con la red) → `1.6.0`-`1.13.1` (investigación de pérdida de telemetría: keepalive, timeouts, y sobre todo `WIFI_FORCE_11B`, que llevó la pérdida de 39% a 0,3%) → `1.13.2` (limpieza a inglés) → `1.14.0` (warmup del DHT22 2000→1300 ms) → `1.15.0` (live mode) → `1.16.0` (heartbeat de live). Ver `../STATUS.md` para el detalle de cada uno.

&#x20;

\*\*Consumo medido (2026-08-08/09):\*\* ciclo normal \~47 mAh/día de ventana activa — es un \*\*piso\*\*, porque `system_mA` se muestrea con WiFi asociado pero ocioso y no captura la ráfaga de asociación. \*\*Live mode: \~53 mAh por hora\*\*, o sea que una hora de live cuesta como 1,1 días de operación normal. El consumo en deep sleep sigue \*\*sin medir\*\*.

&#x20;

Sistema desplegado y funcionando al aire libre, en el fondo del terreno (lote angosto 12×35m, casa al extremo sur, frente de calle al norte), a la altura especificada para mediciones meteorológicas estándar. Ubicación GPS exacta no documentada todavía en ningún archivo del proyecto.

&#x20;

\*\*Sensores activos:\*\*
\- SHT31-D + BMP180 — en los platos exteriores de la Stevenson screen ✅
\- Rain sensor — montado justo arriba de la caja estanca, con leve inclinación ✅
\- Fotoresistor — dentro de la caja estanca, mirando por una ventanita cortada en la caja para tomar luminosidad ✅
\- DS18B20 (temp\_sistema) — mide temperatura de la caja estanca. ⚠️ falla intermitente (ver abajo)
\- INA219 sistema + INA219 solar + módulo MPPT CN3791 — todos dentro de la caja estanca, cargando la batería. ⚠️ INA solar falla intermitente (ver abajo)

&#x20;

\*\*Removido / no instalado:\*\*
\- AS5600 (veleta) — nunca se conectó. JST5 sigue sin nada conectado. No se empezaron las pruebas de veleta ni anemómetro en campo (el diseño/calibración de "The Windicator V1" existe en papel, pendiente de instalación física).

&#x20;

\*\*Reemplazado y en servicio:\*\*
\- DHT11 → DHT22 — el DHT11 murió (falla crónica, venía fallando ya en proyectos anteriores a esta estación). \*\*2026-07-25:\*\* reemplazo físico completado — se desoldó el DHT11 del módulo Sunfounder y se soldó en su lugar el sensor DHT22 pelado, reutilizando el PCB del módulo (mismo pull-up y filtro ya incluidos ahí, mismo orden de pines VDD-DATA-NC-GND y mismo paso de 2.54mm que el DHT11, mismo conector JST y pin GPIO0 de la placa principal — sin cambios de cableado ni de PCB). Documentado con fotos antes/después del desoldado. \*\*Flasheado y validado en campo el 2026-07-25 — issue cerrado.\*\* Los campos MQTT conservan el nombre histórico `dht11_*` a propósito, para no partir la serie en InfluxDB. Detalle en `../STATUS.md`.

&#x20;

\*\*Sobre el issue de I2C (ver también `../i2c-bus-lockup-investigation.md`):\*\* la causa real no fue el AS5600 (nunca estuvo conectado) sino cold solder joints en las dos perfboards del primer prototipo. Resoldar varias juntas mejoró muchísimo el problema — antes era mucho más crítico (bus I2C se caía random, afectaba INA y más sensores). Ahora solo fallan intermitentemente el INA219 solar y el DS18B20, probablemente por juntas frías remanentes sin resoldar todavía.

&#x20;

\---

&#x20;

\## PCB v2 — en fabricación (actualizado 2026-07-11)

&#x20;

Versión definitiva en desarrollo para reemplazar el prototipo de dos perfboards de arriba y resolver el problema de cold solder joints. **Corresponde a los layouts documentados en este archivo** (secciones "Placa principal — 31×26 holes" y "Placa auxiliar JST — 24×10 holes" más abajo) — diseñados en Fritzing (`Main PCB - ... IoT_v1.4.fzz`, `Aux PCB - ... IoT_v1.2.2.fzz`, raíz de este repo) y fabricados como PCB FR4 simple faz caseras, por transferencia de tóner + cloruro férrico. Los exports de fabricación (capas etch/mask/silk, por intento) están en `PCB/`.

&#x20;

\*\*Estado del armado:\*\* ambas placas (main + aux) perforadas, soldadura de componentes en curso — no terminada todavía.

&#x20;

\*\*Protección contra humedad/estrés térmico — EJECUTADA, doble capa de barniz aplicada.\*\* El procedimiento que se siguió (antes de instalar los módulos enchufables): terminar de soldar todos los componentes → limpiar residuos de flux con alcohol isopropílico → enmascarar con cinta los headers hembra donde van INA219/ESP32 (para que el barniz no llegue a los contactos) → aplicar Flux Protector (ContactFlux) y barniz dielectrico (Delta) sobre toda la placa ya soldada → dejar curar → recién ahí insertar los módulos en los headers.

&#x20;

Importa para interpretar la telemetría: el DHT22 de la caja quedó como monitor de integridad del sellado, y cuando marca humedad alta adentro la pregunta ya no es si la electrónica está expuesta —está barnizada— sino si entró agua que hay que sacar. Ver `../STATUS.md` → "Humedad dentro de la caja".

&#x20;

\---

&#x20;

\## Hardware principal

&#x20;

| Componente | Modelo | Notas |

|---|---|---|

| Microcontrolador | ESP32-C3 SuperMini | 5V via boost, 3.3V I/O |

| Sensor T+H exterior | SHT31-D | I2C 0x44, en plato exterior |

| Sensor presión | BMP180 | I2C 0x77, en plato exterior |

| Monitor corriente solar | INA219 | I2C 0x41 |

| Monitor corriente sistema | INA219 | I2C 0x40 |

| Cargador solar MPPT | CN3791 | Off-board, conectado por cable |

| Step-up boost | — | Calibrado a 5V, alimenta ESP32 |

| Batería | LiPo 1500mAh | Conecta directo a CN3791 (JST PH 1.25mm) |

| Panel solar | 5.2W \~24-cell | 210×165mm, diseñado para carga directa 12V, Voc=14.2V, Vmp≈11-12V |

| Caja estanca | — | 190×140×70mm |

| Mástil | PVC 3/4" marrón | — |

&#x20;

\---

&#x20;

\## GPIOs asignados — ESP32-C3 SuperMini

&#x20;

| GPIO | Señal | Tipo | Rail | Notas |

|---|---|---|---|---|

| GPIO0 | DHT22 DATA (ex DHT11) | Digital 1-wire | Rail B | Sensor reemplazado físicamente 2026-07-25, firmware adaptado — falta flashear. Ver "Estado actual en campo" |

| GPIO1 | Pluviómetro SIGNAL | Interrupt | Always-on | Reed switch, pull-up interno |

| GPIO2 | Anemómetro SIGNAL | Interrupt | Always-on | Reed switch, normalmente abierto → safe boot |

| GPIO3 | Fotoresistor ADC | ADC1\_CH3 | Rail B | — |

| GPIO4 | Rain sensor AO | ADC1\_CH4 | Rail B | JTAG MTMS como entrada en boot → sin conflicto |

| GPIO5 | SCL | I2C clock | — | Bus I2C compartido |

| GPIO6 | SDA | I2C data | — | Bus I2C compartido |

| GPIO7 | Rail A NPN base | Digital out | — | BC337 low-side switch sensores primarios |

| GPIO8 | Rail B NPN base | Digital out | — | BC337 low-side switch sensores secundarios. GPIO8 LOW en boot → Rail B OFF al arrancar ✅ |

| GPIO10 | DS18B20 DATA | 1-Wire | Always-on | Pull-up incluido en módulo Sunfounder |

&#x20;

\*\*GPIOs libres:\*\* GPIO9 (⚠️ botón BOOT físico — no usar), GPIO20, GPIO21

&#x20;

\---

&#x20;

\## I2C bus

&#x20;

\- \*\*SDA:\*\* GPIO6 — cable verde (color UTP)

\- \*\*SCL:\*\* GPIO5 — cable verde/blanco (color UTP)

\- \*\*Pull-ups externos:\*\* 2× 4.92kΩ (SDA→3.3V y SCL→3.3V) soldados en placa principal

\- \*\*Motivo:\*\* pull-ups internos del ESP32-C3 insuficientes para la capacitancia del cable UTP de \~1.5m al plato exterior

\### Dispositivos I2C

&#x20;

| Dirección | Dispositivo | Ubicación |

|---|---|---|

| 0x40 | INA219 system | Placa principal |

| 0x41 | INA219 solar | Placa principal |

| 0x44 | SHT31-D | Plato exterior (via UTP) |

| 0x77 | BMP180 | Plato exterior (via UTP) |

| 0x36 | AS5600 veleta | ⚠️ Nunca conectado — en duda, ver "Componentes pendientes de instalación" (posible alternativa óptica) |

&#x20;

\---

&#x20;

\## Switching de rails — BC337 NPN low-side

&#x20;

Dos transistores BC337 (pinout C-B-E con plano al frente) controlan el GND de los sensores. hFE medido: 250 y 263 en las unidades del prototipo perfboard; 226 en la unidad montada en la PCB Main v1.4. El rango de spec del BC337-25 es 160–400 y el valor depende de la corriente de test del tester — cualquier valor de ese orden está sobrado (se necesita hFE ≥ 4).

&#x20;

\### ⚠️ Orientación física — footprint de Fritzing con serigrafía inconsistente

&#x20;

**El footprint de transistor bipolar de Fritzing (TO92 THT, tipo "NPN (CBE)") tiene la D de la serigrafía dibujada de forma inconsistente con el orden C-B-E de los pads.** Un BC337 real insertado siguiendo la panza de la serigrafía queda con **colector y emisor cruzados**.

&#x20;

En la Main v1.4 esto pasó con Q1 RAIL1 y Q2 RAIL2 — ambos quedaron invertidos. Detectado midiendo continuidad en la placa armada (emisor al bus, colector a tierra). Corregido desoldando y rotando los dos transistores 180° sobre su eje vertical (la base queda en el mismo agujero, las patas externas intercambian lugar).

&#x20;

**Regla de armado:** insertar el BC337 con la parte plana **al revés de lo que marca la serigrafía**.

&#x20;

Notas de diagnóstico, por si reaparece:

&#x20;

\- El cobre y el esquemático de Fritzing **son correctos** — verificado por continuidad (GND, VCC, SDA, SCL, e inter-board contra la aux) y por el esquemático (emisor→tierra). El error es solo del silkscreen del footprint.

\- Cambiar el dropdown de tipo a "NPN (EBC)" **no sirve como fix**: Fritzing intenta invertir las pistas del PCB, porque el swap C/E está acoplado entre esquemático y PCB.

\- Síntoma eléctrico si queda invertido: el transistor opera en modo activo inverso (hFE ~2–5 en vez de 226), con Vce(sat) degradado. El "GND" del rail no queda en 0V sino flotando algunos cientos de mV, de forma variable — referencia sucia para los sensores I2C.

\- Verificación rápida con tester en modo diodo: punta roja en la pata del **centro** (base en ambas convenciones), negra en cada lateral. El que da la caída levemente **mayor** es el emisor, y va a GND del sistema.

&#x20;

\### Circuito (idéntico para Rail A y Rail B)

&#x20;

```

GPIO ──\[2.13kΩ]──┬── Base BC337

&#x20;                │

&#x20;             \[9.9kΩ]

&#x20;                │

&#x20;               GND

&#x20;

VCC sensores (siempre conectado)

&#x20;     │

&#x20; \[sensor]

&#x20;     │

&#x20; GND sensor ── Collector BC337

&#x20;                    │

&#x20;              Emitter BC337

&#x20;                    │

&#x20;                GND sistema

```

&#x20;

| Parámetro | Valor |

|---|---|

| R base | 2.13kΩ (nominal 2.2kΩ, tolerancia 3%) |

| R pull-down | 9.9kΩ (nominal 10kΩ, tolerancia 1%) |

| Ib | 1.22mA |

| Ic máxima estimada | \~5mA |

| hFE necesario | 4 → BC337 en saturación profunda ✅ |

&#x20;

\### Rail A — sensores primarios (GPIO7)

Activo en tiers 1, 2 y 3. Se apaga en tier 4.

\- SHT31-D + BMP180 (via UTP)

\### Rail B — sensores secundarios (GPIO8)

Activo solo en tier 1. Se apaga en tier 2.

\- DHT11

\- Rain sensor (placa sensora directa, sin módulo Sunfounder)

\- Fotoresistor

\- AS5600 veleta (pendiente instalación)

\### Always-on (sin switching)

\- DS18B20 (temperatura enclosure)

\- Anemómetro (reed switch)

\- Pluviómetro (reed switch)

\---

&#x20;

\## Tiers de energía por voltaje de batería

&#x20;

| Tier | Voltaje | Estado |

|---|---|---|

| 1 | ≥ 4.10V | Operación completa. Rail A + Rail B ON |

| 2 | 3.90–4.10V | Rail A ON · Rail B OFF |

| 3 | 3.75–3.90V | Solo SHT31+BMP180 cada 5min |

| 4 | < 3.75V | Heartbeat cada 30min. Todo OFF |

&#x20;

> ⚠️ **Esto es diseño en papel, no está implementado** (verificado contra el firmware el 2026-07-29). `src/battery.h` existe pero está vacío, `SLEEP_INTERVAL_SEC` es fijo en 60 s, `sensors_railsOn()` enciende los dos rails incondicionalmente, y el comando `config` por MQTT se parsea pero es un stub. Los umbrales de la tabla son la intención, no el comportamiento actual.
>
> **Corrección de premisa, importante si se retoma**: los tiers **no ahorran nada durante el deep sleep**. GPIO7 y GPIO8 no son RTC GPIOs en el ESP32-C3 (sólo GPIO0–5 lo son), así que al dormir quedan sin drive y el pull-down de 9,9 kΩ de la base del BC337 corta los dos rails por su cuenta. Lo que los tiers recortan es la ventana despierta, donde los rails son ~2-3 mA contra los 51,2 mA medidos del sistema completo. El ahorro real de este diseño está en los tiers 3 y 4, que cambian el **intervalo de sleep** — no en el switching de rails.

Tiers configurables via MQTT `config` sin reflash (pendiente: el comando existe pero no está implementado).

&#x20;

\---

&#x20;

\## Circuito rain sensor (sin módulo Sunfounder)

&#x20;

Se prescinde del módulo completo. Solo se usa la placa sensora conectada directamente.

&#x20;

```

3V3

&#x20;│

\[R1 9.9kΩ]─┐

\[R2 9.9kΩ]─┴──── nodo señal+ ──── GPIO4 (ADC)

(paralelo = 4.95kΩ)   │

&#x20;                   \[C1 100nF]

&#x20;                      │

&#x20;                   Rail B GND ──── placa sensora pin 2

```

&#x20;

\- R1 ∥ R2 = 4.95kΩ pull-up (impedancia fuente óptima para ADC)

\- C1 100nF cerámico (marcado "104"): filtra ruido 50Hz del cable de 1.5m

\- Salida: solo AO analógica. DO descartado (redundante con lectura ADC por firmware)

\---

&#x20;

\## Placa principal — 31×26 holes

&#x20;

\### Zonas

&#x20;

| Zona | Cols | Rows | Contenido |

|---|---|---|---|

| INA219 #1 Solar | cols 1–9 | rows 1–10 | Header 6× hembra col 9, rows 3–8 — \*\*I2C 0x41\*\* |

| INA219 #2 System | cols 10–18 | rows 1–10 | Header 6× hembra col 18, rows 3–8 — \*\*I2C 0x40\*\* |

| JST Solar + CN3791 | 19–31 | 1–10 | 2× JST 2p acceso superior derecho |

| Step-up boost | 1–14 | 11–16 | 4 pines (VIN col 1, VOUT col 14) |

| ESP32-C3 SuperMini | 15–21 | 11–18 | 8× hembra col 15 + 8× hembra col 21 |

| NPN A + resistencias | 23–27 | 12–14 | BC337 Rail A |

| NPN B + resistencias | 23–27 | 16–18 | BC337 Rail B |

| Pull-ups I2C | 28–29 | 22–25 | R\_SCL (28) y R\_SDA (29) |

| Buses | — | 22–25 | SCL·SDA·GND·3V3 full width |

| Header inter-board | 10–21 | 26 | Macho 1×12, borde inferior |

&#x20;

\### Buses

&#x20;

| Fila | Señal |

|---|---|

| 22 | SCL |

| 23 | SDA |

| 24 | GND |

| 25 | 3V3 |

| 26 | Header inter-board 1×12 (cols 10–21) |

&#x20;

\---

&#x20;

\## Placa auxiliar JST — 24×10 holes

&#x20;

\### Conectores JST

&#x20;

⚠️ **Orientación:** en la PCB v2 los JST habían quedado montados 180° invertidos respecto del prototipo perfboard v1. Se dieron vuelta todos y quedó correcto. Al armar una placa nueva, verificar la orientación del conector contra el pinout de esta tabla antes de soldar — el orden de pines de abajo asume la orientación ya corregida.

&#x20;

| # | Conector | Pines | Pinout | Rail | Ubicación |

|---|---|---|---|---|---|

| 1 | UTP SHT31+BMP180 | 4 | VCC · GND\_A · SCL · SDA | Rail A | cols 2–5, fila 3 |

| 2 | Rain sensor | 2 | señal+ · señal− | Rail B | cols 7–8, fila 3 |

| 3 | DHT11 | 3 | VCC · GND\_B · DATA | Rail B | cols 11–13, fila 3 |

| 4 | Fotoresistor | 3 | VCC · GND\_B · ADC | Rail B | cols 15–17, fila 3 |

| 5 | Veleta AS5600 | 5 | VCC · GND\_B · SCL · SDA · DIR | Rail B | cols 19–23, fila 3 |

| 6 | DS18B20 | 3 | VCC · GND · DATA | Always-on | cols 2–4, fila 7 |

| 7 | Anemómetro | 3 | VCC · GND · SIGNAL | Always-on | cols 6–8, fila 7 |

| 8 | Pluviómetro | 3 | VCC · GND · SIGNAL | Always-on | cols 10–12, fila 7 |

&#x20;

\### Pulsadores de diagnóstico

&#x20;

| Pulsador | Cols | Rows | GPIO | En paralelo con |

|---|---|---|---|---|

| BTN\_ANE | 15–19 | 7–10 | GPIO2 | Anemómetro (JST7 SIGNAL) |

| BTN\_PLU | 20–24 | 7–10 | GPIO1 | Pluviómetro (JST8 SIGNAL) |

&#x20;

Footprint: 5 cols × 4 rows. Pines en las 4 esquinas.

P1 = señal GPIO. P2 = GND. Se cierra al presionar.

&#x20;

\### DIR veleta AS5600

\- Hardwired a GND vía puente de estaño en holes (23,4)→(23,5)

\- Pad de acceso externo en col 24 borde derecho

\- Para invertir: cortar puente con bisturí, conectar (23,4) a 3V3

\---

&#x20;

\## Header inter-board 1×12

&#x20;

Macho en placa principal (fila 26, cols 10–21).

Hembra en placa auxiliar (fila 1, cols 7–18).

&#x20;

| Pin | Col principal | Col auxiliar | Señal | GPIO |

|---|---|---|---|---|

| 1 | 10 | 7 | GND | — |

| 2 | 11 | 8 | 3V3 | — |

| 3 | 12 | 9 | SCL | GPIO5 |

| 4 | 13 | 10 | SDA | GPIO6 |

| 5 | 14 | 11 | Rail A GND | NPN A collector |

| 6 | 15 | 12 | Rail B GND | NPN B collector |

| 7 | 16 | 13 | Anemómetro | GPIO2 |

| 8 | 17 | 14 | Pluviómetro | GPIO1 |

| 9 | 18 | 15 | DHT11 | GPIO0 |

| 10 | 19 | 16 | DS18B20 | GPIO10 |

| 11 | 20 | 17 | Fotoresistor ADC | GPIO3 |

| 12 | 21 | 18 | Rain sensor AO | GPIO4 |

&#x20;

\---

&#x20;

\## Componentes pendientes de instalación

&#x20;

| Componente | Estado | Notas |

|---|---|---|

| DHT22 | Instalado físicamente + firmware adaptado (2026-07-25), falta flashear | Reemplazo del DHT11 (murió, falla crónica). Transplante del sensor pelado al módulo Sunfounder original — ver "Estado actual en campo" |

| AS5600 veleta | 🔄 En validación de banco (actualizado 2026-07-25) | Vuelve a ser candidato fuerte: el módulo vino con un imán chico no notado antes (corrige la conclusión previa de incompatibilidad). Conectores dupont ya soldados; prueba en banco con Arduino Mega en curso — primero a mano sin la veleta, después PoC con la veleta montada. Pendiente confirmar si el imán es diametral — ver `aprendizajes_y_roadmap.md` → "Dirección" |

| Alternativa (plan B): disco óptico Gray code | En sourcing | 3× sensores IR reflectivos TCRT5000 (kit Sunfounder "Tracking Sensor") dan posición absoluta (8 posiciones, resolución 45°) al despertar de deep sleep — resuelve la limitación de posición relativa del AS5600. Mau tiene 1 sensor, necesita 2 más. Queda como respaldo si el AS5600 no resuelve en banco |

| PCF8574 (I2C GPIO expander) | Por comprar | 0x20, sin conflicto de bus — necesario para leer los 3× TCRT5000 (P0–P2) si se va por la vía óptica. GPIO20 controlaría LED\_EN vía BC337 |

| 608ZZ bearings | Por comprar | Para anemómetro y veleta |

| Chasis anemómetro+veleta | ✅ Impreso en PLA | STL "Weather Station One" (Printables/MakerWorld, modelo "The Windicator V1"). Pendiente armado mecánico y prueba en campo — todavía no se empezó |

&#x20;

\### Materiales disponibles para armado

\- Reed switch del kit Sunfounder → apto para anemómetro (detección de pulsos)

\- Imanes pequeños disponibles → pueden funcionar para anemómetro (activar reed switch)

\- ⚠️ Falta imán diametral grande específico para AS5600 (veleta de dirección)

\### Pendiente de diseño

\- Definir cómo instalar imanes y sensores en base al diseño de la carcasa impresa

\- Verificar posición del reed switch relativa al rotor del anemómetro

\- Verificar posición del AS5600 relativa al eje de la veleta (distancia óptima al imán: 0.5–3mm)

\---

&#x20;

\## Notas de diseño importantes

&#x20;

\- \*\*`system\_mW` en InfluxDB no es consumo real\*\* — solo captura la fase WiFi activa (\~10s), no el deep sleep (\~54s). Consumo real inferir de estabilidad de voltaje de batería.

\- \*\*I2C sobre UTP requiere pull-ups externos\*\* — 4.92kΩ validados en prueba de campo de 46 horas.

\- \*\*CN3791 MPPT configurado para Vmp real del panel\*\* — verificar R1/R2 del divisor VMP físicamente. Mismatch con panel de 24 celdas (Vmp≈11.5V) inutiliza el MPPT.

\- \*\*El CN3791 cicla carga/corte cuando el pack está lleno, y eso es normal\*\* (medido 2026-08-07, día despejado, 9 h: 14 rachas de carga y 15 de corte). Al cortar el panel sube a \~14,2 V (circuito abierto) con \~6,5 mA; al arrancar baja a \~11,5 V (Vmp bajo carga) con \~200 mA. Es terminación por CV más auto-recarga con histéresis. Las rachas largas (hasta 3,7 h) son la carga real de la mañana; el cicleo corto aparece recién con el pack lleno. \*\*No confundirlo con una falla\*\* — y ojo que hace oscilar el SoC y el estado energético que muestra el dashboard, ver `../STATUS.md`.

\- \*\*El módulo CN3791 tiene dos LEDs de estado y consumen del panel\*\* (confirmado por Mau, 2026-08-09): \*\*rojo\*\* mientras carga, \*\*azul\*\* con la carga completa. \*\*Sólo encienden cuando el panel entrega\*\*, así que no drenan la batería de noche — verificado en los datos: `solar_mA` va a −0,2 mA en la oscuridad.

  El azul es el que se mide fácil, porque es el que queda encendido en la fase de corte donde no hay corriente de carga que lo tape: son los \*\*\~6,5 mA a \~14 V ≈ 90 mW\*\* del piso de esa fase. Sobre las \~2,2 h diarias que el sistema pasa cortado, son del orden de \*\*50 mAh/día equivalentes\*\* en la batería — comparable a todo el consumo diario del nodo (\~47 mAh/día).

  Hoy no duele porque el azul enciende justo cuando sobra energía, y el rojo (menor caída directa, menos consumo) es el que está durante la carga. \*\*El diseño del módulo acertó\*\*: el LED más caro es el que prende cuando la energía es gratis. Pero en una racha de días nublados esos 90 mW salen del presupuesto, así que si alguna vez hay que exprimir autonomía, desoldar el azul es la palanca — misma lógica que la regla de desoldar LEDs de los módulos Sunfounder.

\- \*\*GPIO8 LOW en boot\*\* — deshabilita mensajes ROM por UART0. Sin impacto en operación del firmware.

\- \*\*GPIO9 reservado\*\* — es el botón BOOT físico del ESP32-C3 SuperMini. No conectar.

\- \*\*Módulos Sunfounder: desoldar LEDs\*\* antes de montar en PCB — BMP180 \*\*(hecho)\*\*, \*\*DS18B20 (hecho)\*\*, DHT11, fotoresistor (verificar si tiene). \*\*Los módulos INA219 no tienen LED de alimentación\*\* — verificado el 2026-07-29. \*\*El LED del propio ESP32-C3 SuperMini tampoco está activo\*\* — desoldado (2026-08-02). Importaba porque cuelgan del bus 3V3, que sigue vivo durante el deep sleep: un LED de 1-3 mA por módulo habría consumido más que todo el resto del sistema junto, y no hay firmware que lo apague.

  \*\*Los LEDs quedan entonces descartados como fuente del consumo de reposo\*\* (ver el punto siguiente). El DHT11 y el fotorresistor cuelgan de Rail B, que se apaga al dormir, así que aunque tuvieran LED no cuentan.

\- \*\*Consumo activo medido: 51,2 mA\*\* (mediana del INA219 de sistema sobre 59 muestras de campo, 2026-07-29), con la ventana despierta en 3,3 s por ciclo antes del firmware `1.5.0`. La cifra de ~100 mA que circulaba por los documentos estaba 2× alta. El consumo en deep sleep sigue \*\*sin medir directamente\*\* — el INA219 sólo muestrea con el nodo despierto, y además el firmware lo pone en power-down al dormir, así que \*\*no hay cambio de firmware que pueda resolverlo\*\*: hace falta un multímetro en serie con la batería.

\- ⚠️ \*\*El reposo pesa más que la ventana activa — estimado, sin medir (2026-08-02).\*\* Estimado indirectamente desde la caída de tensión de la batería durante la noche, que integra todo el consumo porque no entra carga: mediana de \*\*5,10 mA\*\* de consumo medio total sobre 5 noches. La ventana activa explica \*\*1,86 mA\*\* (51,2 mA × 3,64% de ciclo de trabajo), así que quedan \*\*~3,2 mA sin explicar, el 63% del total\*\*. En mAh/día: activo 44,7 · resto 77,7 · \*\*total 122,4\*\*.

  \*\*Caveats\*\*: la conversión volts→mAh usa la curva de SoC del backend, que es un indicador y no una contabilidad; y la temperatura baja de noche, lo que sube la resistencia interna, así que parte de la caída puede ser térmica y no consumo. Aun con un factor 2 de error sigue siendo mA, no µA.

  \*\*Qué queda como sospechoso\*\*, ahora que los LEDs están descartados: el \*\*reposo del step-up boost\*\*, que tiene que estar siempre encendido porque alimenta al ESP32 que despierta (los módulos tipo MT3608 están en 0,5-2 mA y empeoran a carga liviana), más el regulador propio de la SuperMini. Los dos INA219 en power-down son ~12 µA y no explican nada.

  \*\*Pendiente\*\*: medirlo con multímetro en serie con la batería, con el nodo dormido, y después el reposo del boost solo con el ESP32 desconectado. Es la medición de mayor valor pendiente del proyecto — decide si tiene sentido optimizar la ventana activa (44,7 mAh/día) o el reposo (77,7 mAh/día).

\- \*\*Los dos INA219 se apagan entre ciclos desde el firmware `1.4.0`\*\* (`sensors_sleepMonitors()`, modo power-down ~6 µA contra ~0,7-1 mA en conversión continua). Cuelgan del bus 3V3 siempre alimentado, así que antes convertían los ~57 s por ciclo en que nadie los lee. El power-down apaga el ADC del chip pero \*\*no abre el shunt\*\*, así que la carga solar por el CN3791 no se ve afectada.

\- \*\*Rain sensor: prescindir del módulo Sunfounder completo\*\* — conectar placa sensora directamente con pull-up 4.95kΩ y filtro 100nF en placa auxiliar.

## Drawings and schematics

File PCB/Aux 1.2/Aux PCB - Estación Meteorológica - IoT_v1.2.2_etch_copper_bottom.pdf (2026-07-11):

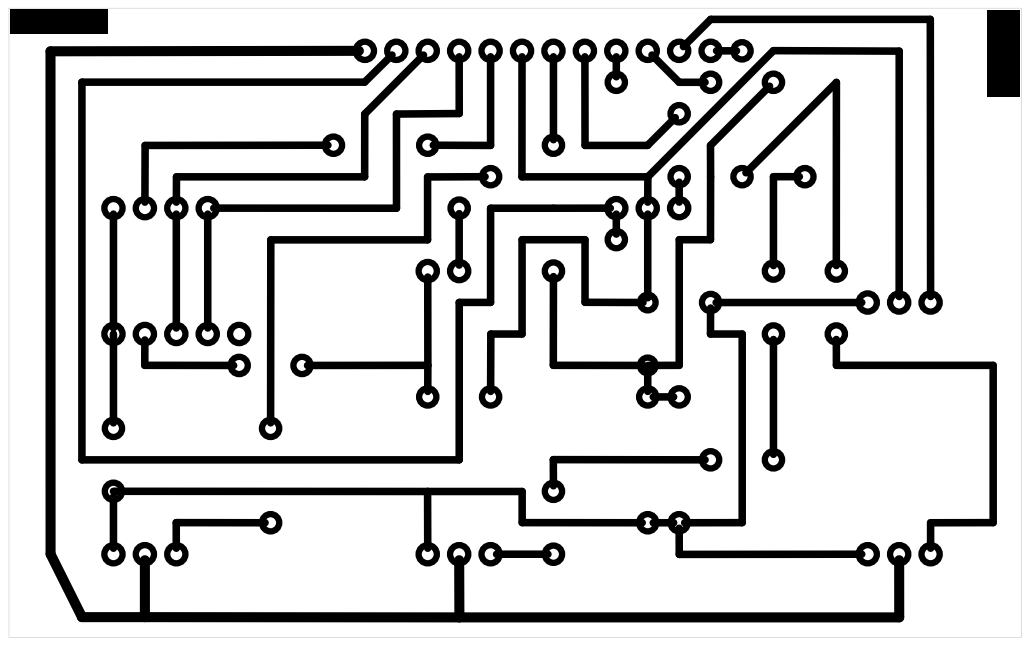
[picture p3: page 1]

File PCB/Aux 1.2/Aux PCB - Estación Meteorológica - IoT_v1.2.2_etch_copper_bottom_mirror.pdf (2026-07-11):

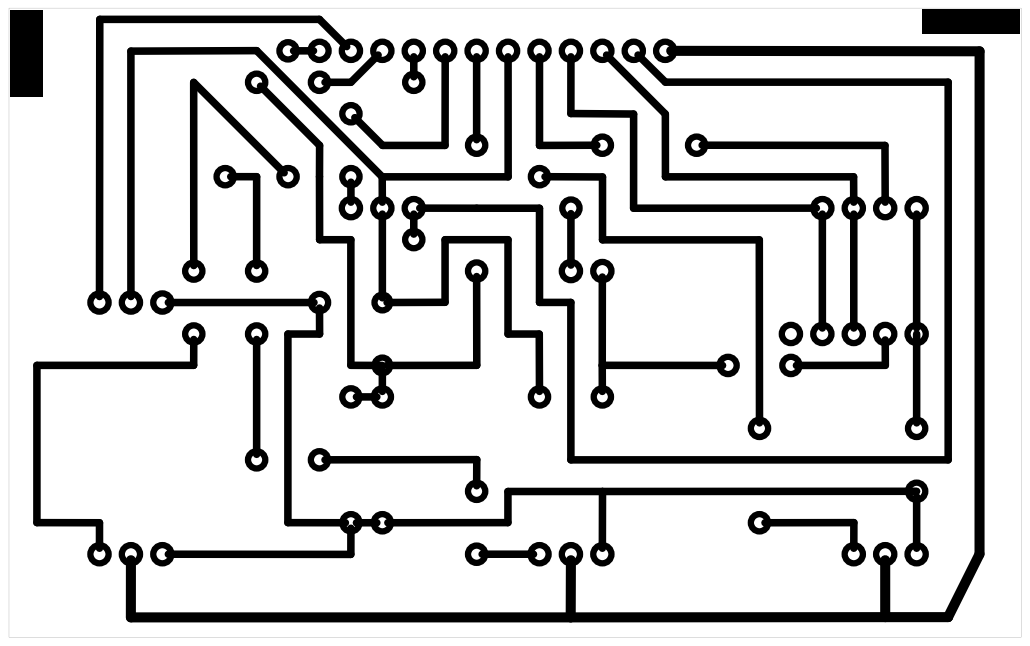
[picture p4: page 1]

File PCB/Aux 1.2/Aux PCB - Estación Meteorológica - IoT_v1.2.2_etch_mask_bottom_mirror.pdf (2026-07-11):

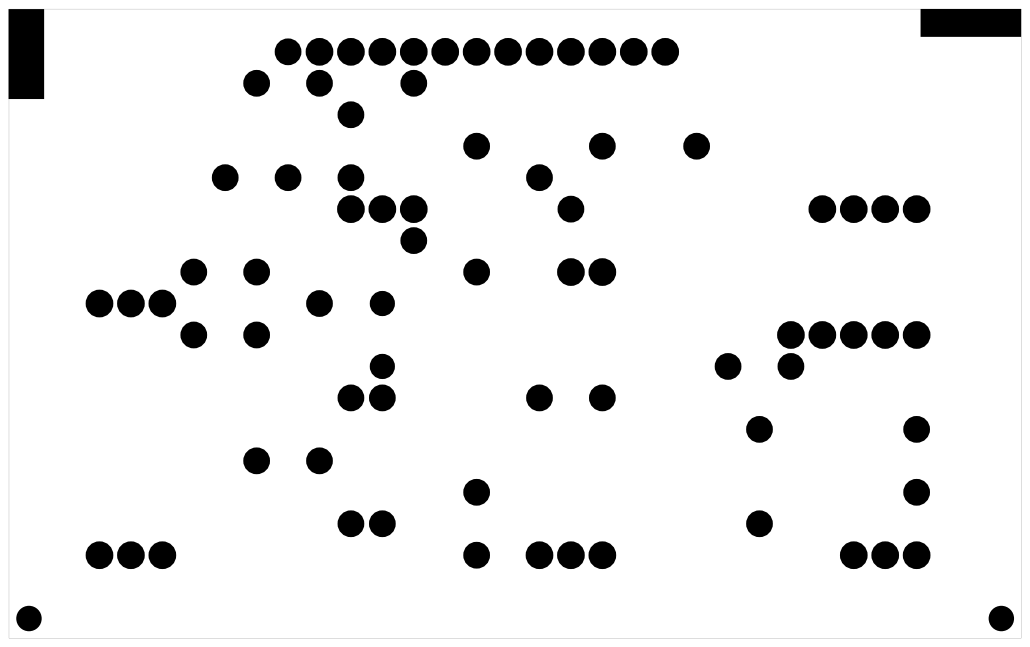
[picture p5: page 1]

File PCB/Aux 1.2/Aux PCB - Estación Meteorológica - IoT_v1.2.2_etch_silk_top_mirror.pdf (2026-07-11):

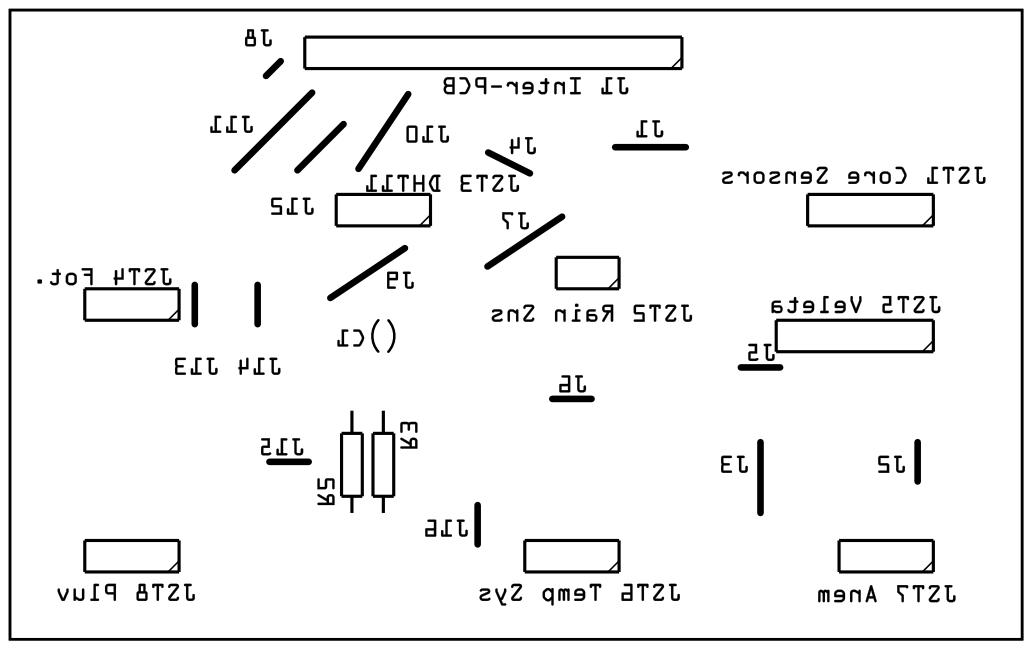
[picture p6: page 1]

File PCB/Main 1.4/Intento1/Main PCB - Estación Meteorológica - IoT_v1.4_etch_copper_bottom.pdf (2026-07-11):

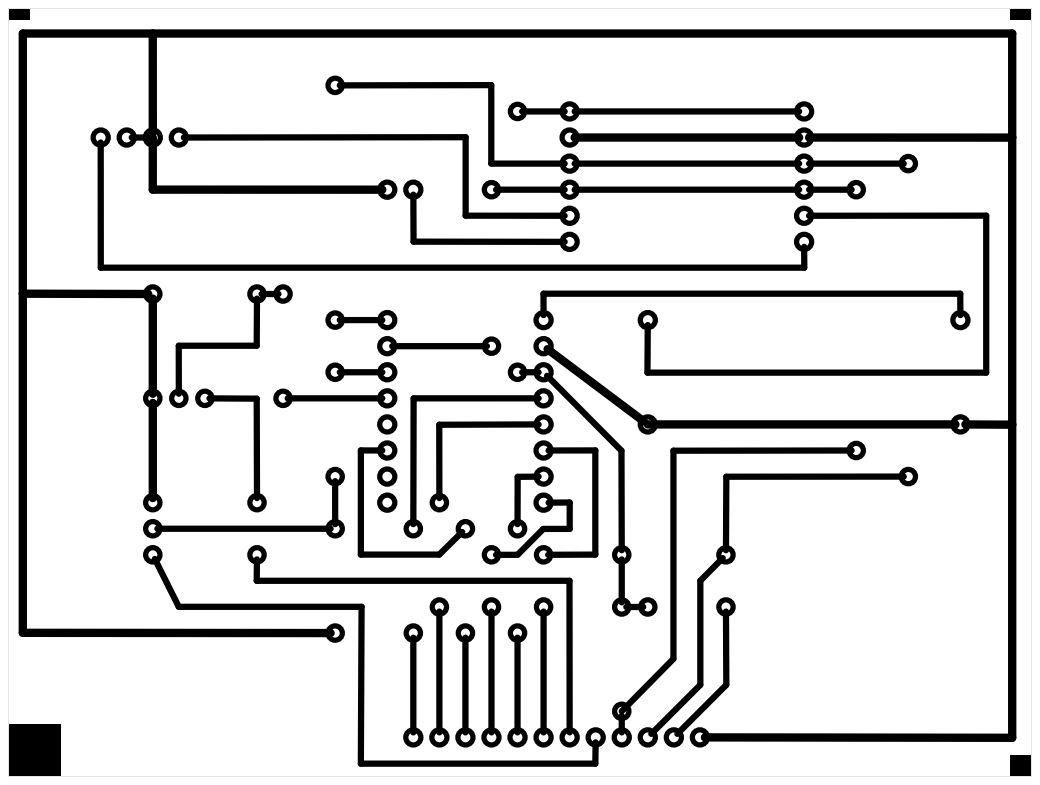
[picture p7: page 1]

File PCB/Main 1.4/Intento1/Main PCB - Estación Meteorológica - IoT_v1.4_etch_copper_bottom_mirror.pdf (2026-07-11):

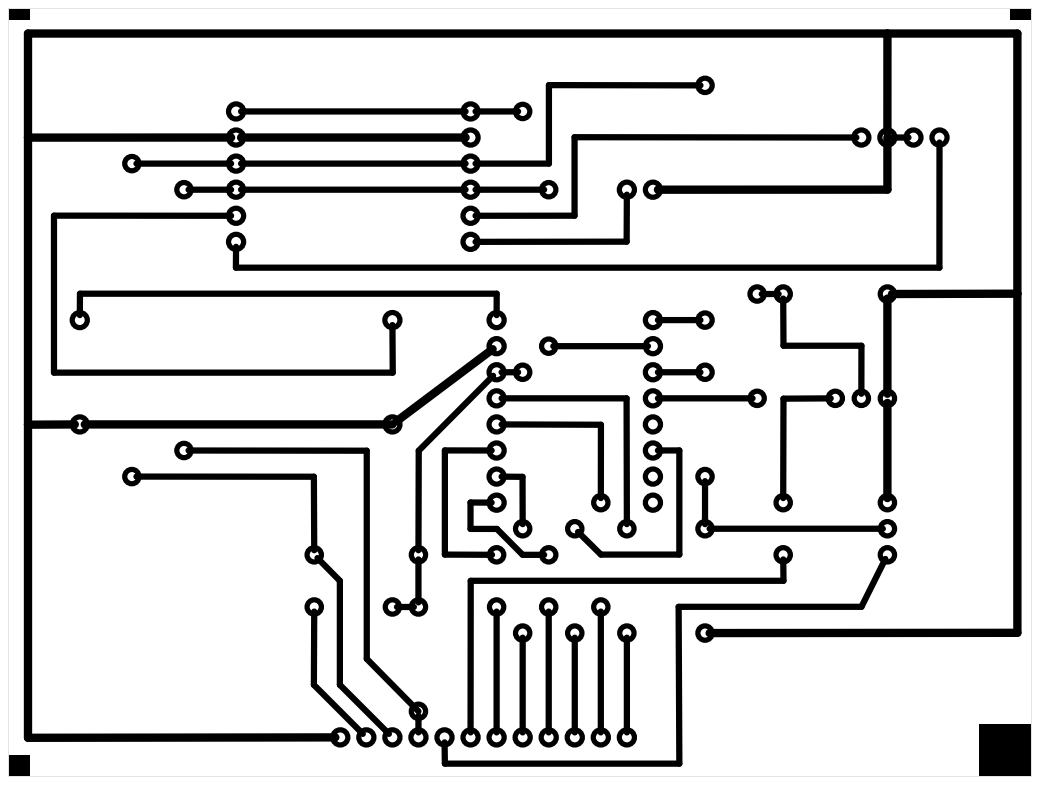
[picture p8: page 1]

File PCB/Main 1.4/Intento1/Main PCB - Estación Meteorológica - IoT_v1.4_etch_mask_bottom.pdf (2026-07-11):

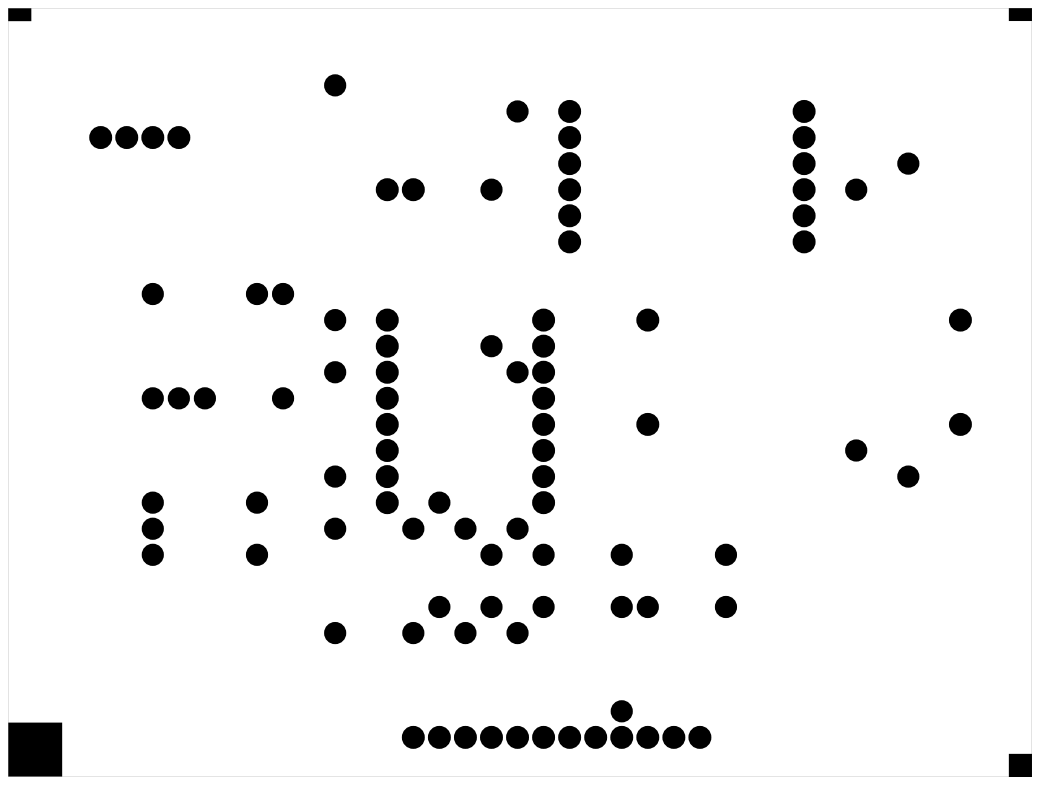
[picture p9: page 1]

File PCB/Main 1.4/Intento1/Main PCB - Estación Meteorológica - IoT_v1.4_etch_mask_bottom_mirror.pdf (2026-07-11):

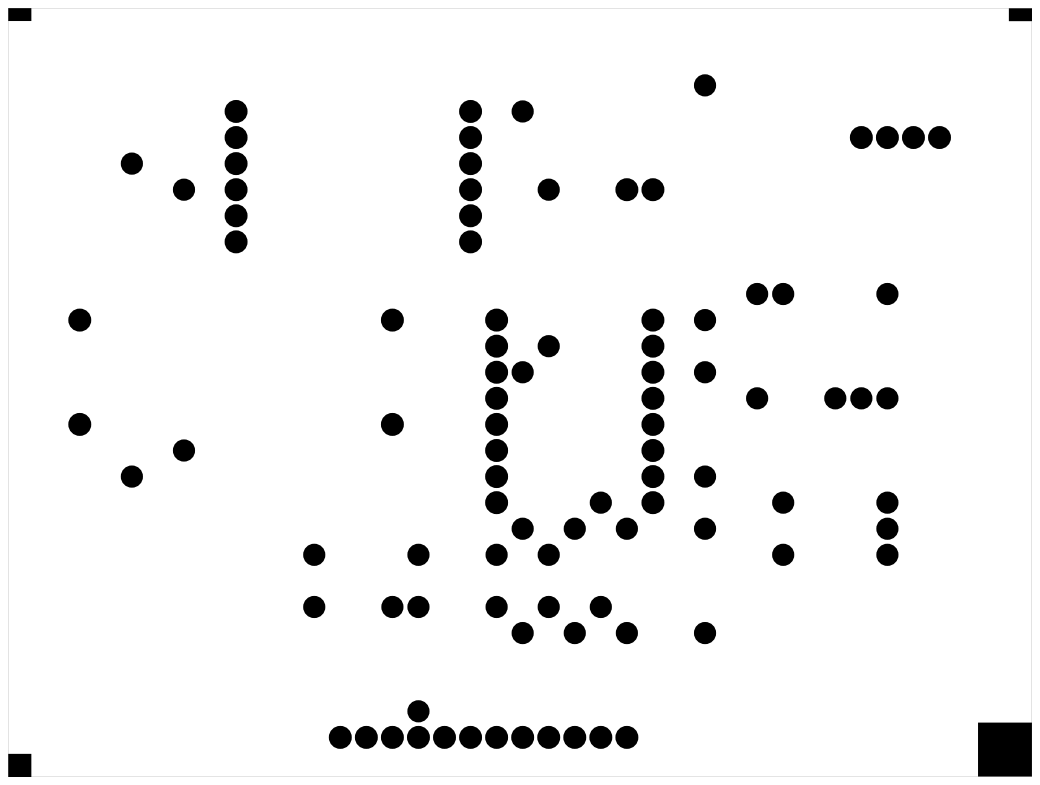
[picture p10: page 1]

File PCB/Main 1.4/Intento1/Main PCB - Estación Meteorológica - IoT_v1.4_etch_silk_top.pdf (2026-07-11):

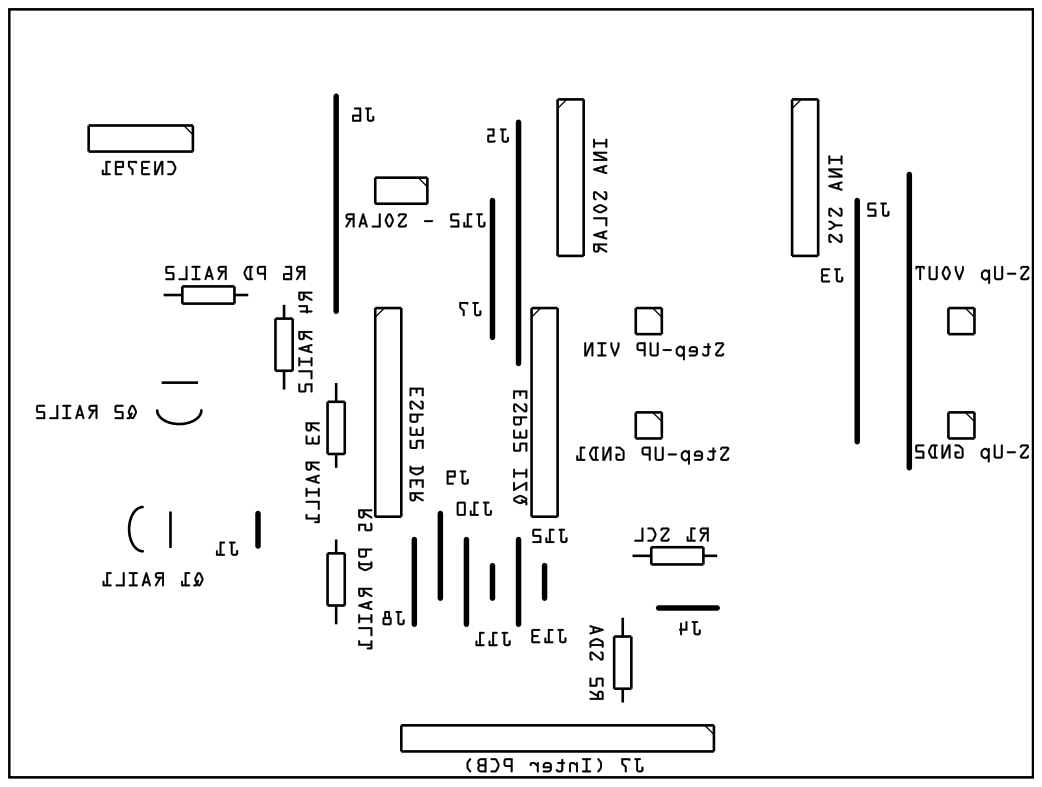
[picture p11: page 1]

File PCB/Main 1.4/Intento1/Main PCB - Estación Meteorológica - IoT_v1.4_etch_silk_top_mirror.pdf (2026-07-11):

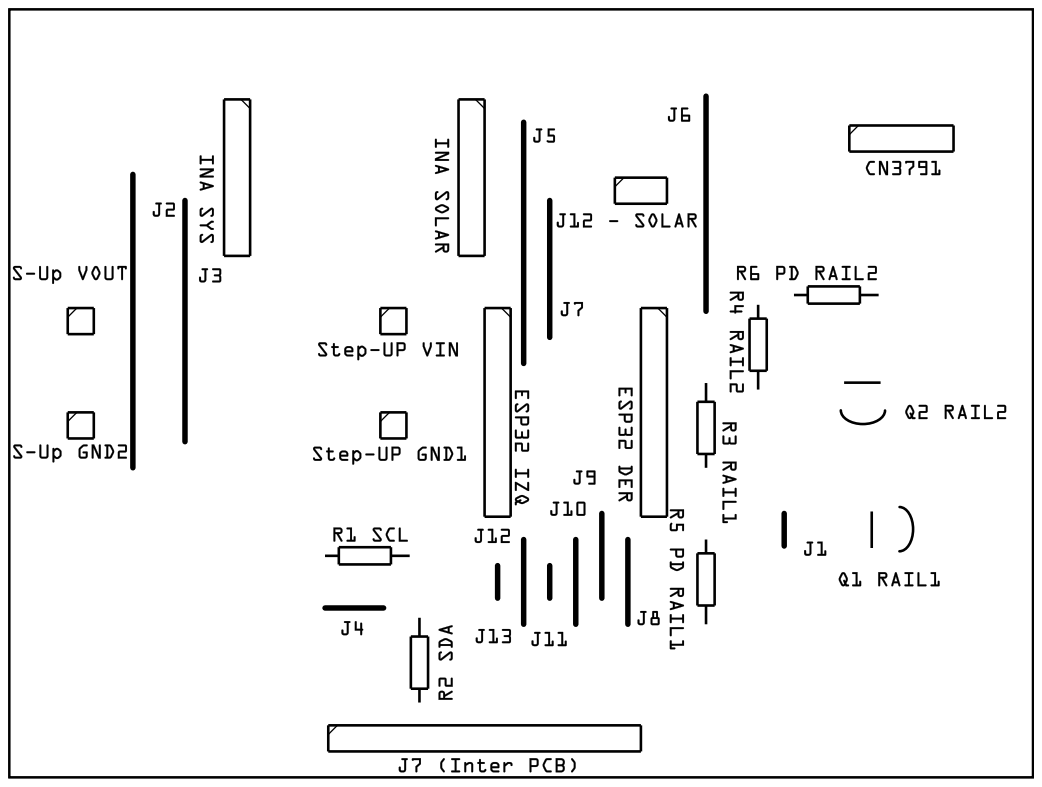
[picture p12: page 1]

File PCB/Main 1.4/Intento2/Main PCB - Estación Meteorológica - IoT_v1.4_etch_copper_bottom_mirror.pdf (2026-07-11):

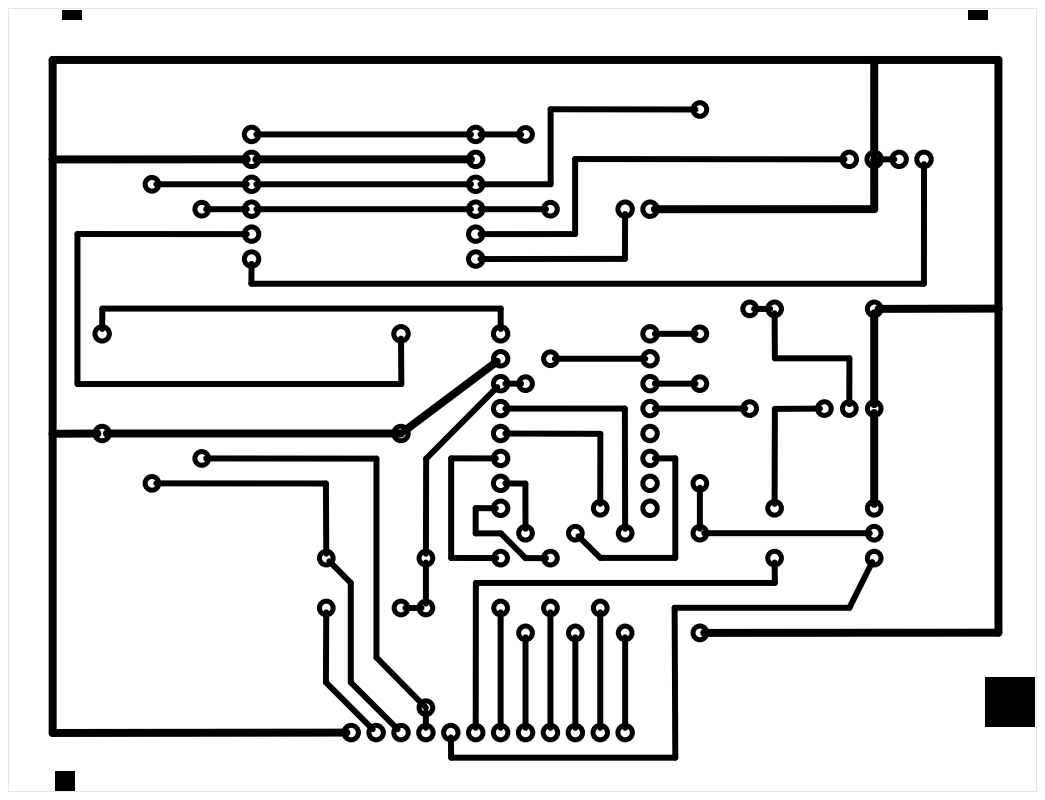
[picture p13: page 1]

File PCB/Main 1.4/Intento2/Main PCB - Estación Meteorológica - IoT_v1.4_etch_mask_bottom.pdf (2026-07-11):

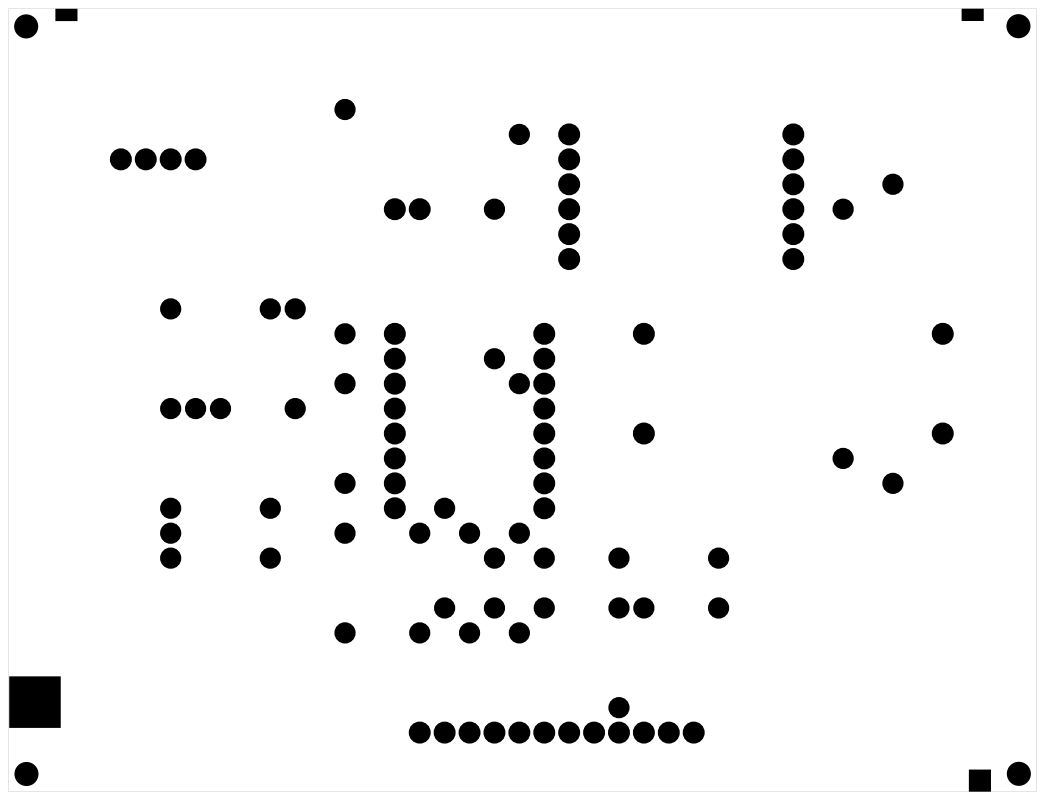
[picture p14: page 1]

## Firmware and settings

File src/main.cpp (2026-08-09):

#include <Arduino.h>
#include <Wire.h>
#include <WiFi.h>
#include <PubSubClient.h>
#include <ArduinoJson.h>

#include "config.h"
#include "command.h"
#include "service_mode.h"
#include "live_mode.h"
#include "sensors.h"
#include "telemetry.h"
#include "logging.h"
#include <esp_system.h>
#include <esp_wifi.h>   // esp_wifi_set_protocol — see WIFI_FORCE_11B in config.h

// ─── Global clients ───────────────────────────────────────────────────────────
WiFiClient   wifiClient;
PubSubClient mqtt(wifiClient);

// ─── RTC state for the normal cycle ───────────────────────────────────────────
RTC_DATA_ATTR uint32_t rtc_bootCount    = 0;
RTC_DATA_ATTR uint8_t  rtc_wifiChannel  = 0;
RTC_DATA_ATTR uint8_t  rtc_wifiBssid[6] = {0};

// ─── Buffers for MQTT command (filled in the callback) ────────────────────────
static String  pendingCmdPayload = "";
static bool    cmdReceived       = false;

// ─── Prototypes ───────────────────────────────────────────────────────────────
bool  connectWiFi();
bool  connectMQTT();
void  mqttCallback(char* topic, byte* payload, unsigned int length);
Command waitForRetainedCommand();
void  handleCommand(const Command& cmd);
void  clearRetainedCommand();
void  goToDeepSleep();

// ═════════════════════════════════════════════════════════════════════════════
void setup() {
    #if LOG_LEVEL > 0
        Serial.begin(115200);
        delay(2000);
        Serial.println("=== Boot ===");
    #endif

    rtc_bootCount++;
    LOG_V("=== Boot #%u ===  Firmware: %s", rtc_bootCount, FIRMWARE_VERSION);

    // Before the first logging_write(): the logging state lives in
    // `.rtc_noinit`, which starts out garbage on power-on.
    logging_begin();

    // The reset reason distinguishes a normal wake from a panic, a watchdog
    // or a brownout. It's free and today there's no way to know it in the
    // field — brownout is a live hypothesis given the solar/battery situation.
    //
    // It also marks where rtc_bootCount got reset: that counter lives in
    // `.rtc.data` and gets wiped on any reset that isn't a deep sleep wake,
    // while the ring now survives. So an entry with reset != 8 is the
    // boundary between two lifetimes of the counter, and the backend needs
    // it to avoid misdating whatever is left on the other side.
    logging_write(LOG_BOOT, 0, (int16_t)esp_reset_reason());

    Wire.begin(I2C_SDA, I2C_SCL);

    // ── If we were in service mode before the restart, resume immediately
    if (serviceMode_isActive()) {
        LOG_V("RTC indicates active service mode — resuming without reading MQTT");
        if (!connectWiFi()) { goToDeepSleep(); return; }
        // connectMQTT()'s return value is deliberately ignored: this path is
        // the one after a reflash, and serviceMode_run() brings up ArduinoOTA
        // even without a broker. Aborting here if MQTT fails would close the
        // OTA window exactly when it's needed most — if the new firmware came
        // out broken, the only way to fix it remotely is for that window to
        // open anyway. No MQTT means no heartbeats, but flashing still works.
        connectMQTT();
        // Create a dummy Command so evaluate() goes straight into run()
        Command resumeCmd;
        resumeCmd.type        = CommandType::MAINTENANCE;
        resumeCmd.timeout_min = rtc_serviceTimeoutMin;
        resumeCmd.valid       = true;
        serviceMode_evaluate(mqtt, resumeCmd);
        return;
    }

    // ── Normal cycle ──────────────────────────────────────────────────────────
    // As early as possible on this path: the DHT22 needs ~2 s to stabilize
    // after getting power, and while the rail-on lived inside sensors_init()
    // —which runs after WiFi, MQTT and the retained-command wait— those 2 s
    // were paid in full at the end of the cycle, with the radio associated.
    // That was 61% of the 3.3 s awake window measured in the field on
    // 2026-07-28. Here the warmup happens in parallel with work that had to
    // be done anyway.
    //
    // Goes AFTER the service mode early-return on purpose: that path doesn't
    // touch the rails today, and a session can last up to 60 min. Turning
    // them on there would leave the rain sensor with continuous voltage on
    // the electrodes for the whole session, which is exactly the
    // electrolytic corrosion the pulsed reading avoids.
    sensors_railsOn();

    if (!connectWiFi()) { goToDeepSleep(); return; }
    if (!connectMQTT()) { goToDeepSleep(); return; }

    // Read the broker's retained command (wait up to MQTT_RETAINED_WAIT_MS)
    Command cmd = waitForRetainedCommand();

    // Initialize sensors only on a normal cycle (not in service mode or reboot)
    sensors_init();

    // ── Dispatch by command ───────────────────────────────────────────────────
    handleCommand(cmd);
}

void loop() {
    // Not used: the device exits via deep sleep or restart
}

// ═════════════════════════════════════════════════════════════════════════════
// WiFi connection
// ═════════════════════════════════════════════════════════════════════════════
bool connectWiFi() {
    const uint32_t wifiStartMs = millis();
    WiFi.mode(WIFI_STA);

    // Before WiFi.begin(): the power save mode applies to the association
    // that follows, and with the default (modem sleep) the association dies
    // mid-cycle. See WIFI_POWER_SAVE in config.h for the measurement that
    // led here.
    WiFi.setSleep(WIFI_POWER_SAVE ? true : false);

#if WIFI_FORCE_11B
    // Goes after WiFi.mode(), which is what initializes and starts the
    // driver: esp_wifi_set_protocol() fails with ESP_ERR_WIFI_NOT_STARTED if
    // called before that. See WIFI_FORCE_11B in config.h — it comes from the
    // sniffer decoding the node's management frames (1 Mbps) and not a
    // single one of its data frames (OFDM), at the same distance and the
    // same moment.
    esp_err_t rate_err = esp_wifi_set_protocol(WIFI_IF_STA, WIFI_PROTOCOL_11B);
    if (rate_err != ESP_OK) {
        LOG_E("Could not force 802.11b: %d", (int)rate_err);
    }
#endif

    // Static IP
    if (!WiFi.config(WIFI_STATIC_IP, WIFI_GATEWAY, WIFI_SUBNET, WIFI_DNS)) {
        LOG_E("Failed to configure static IP");
    }

    for (int attempt = 1; attempt <= WIFI_MAX_RETRIES; attempt++) {
        logging_write(LOG_WIFI_TRY, (uint8_t)attempt,
                      (attempt == 1) ? (int16_t)rtc_wifiChannel : 0);

        // First attempt uses the cache if available; the rest scan
        if (attempt == 1 && rtc_wifiChannel > 0) {
            LOG_V("WiFi: attempt %d/%d (cached channel %d)", attempt, WIFI_MAX_RETRIES, rtc_wifiChannel);
            WiFi.begin(WIFI_SSID, WIFI_PASSWORD, rtc_wifiChannel, rtc_wifiBssid, true);
        } else {
            LOG_V("WiFi: attempt %d/%d (scan)", attempt, WIFI_MAX_RETRIES);
            rtc_wifiChannel = 0;
            WiFi.disconnect(false);
            delay(100);
            WiFi.begin(WIFI_SSID, WIFI_PASSWORD);
        }

        uint32_t start = millis();
        while (WiFi.status() != WL_CONNECTED) {
            if (millis() - start > WIFI_TIMEOUT_MS) break;
            delay(200);
        }

        if (WiFi.status() == WL_CONNECTED) {
            rtc_wifiChannel = WiFi.channel();
            memcpy(rtc_wifiBssid, WiFi.BSSID(), 6);
            LOG_V("WiFi OK — IP: %s  channel: %d  attempt: %d", WiFi.localIP().toString().c_str(), rtc_wifiChannel, attempt);
            logging_write(LOG_WIFI_OK, (uint8_t)attempt, (int16_t)WiFi.RSSI());
            return true;
        }

        LOG_E("WiFi timeout (attempt %d/%d)", attempt, WIFI_MAX_RETRIES);
        logging_write(LOG_WIFI_FAIL, (uint8_t)attempt, (int16_t)WiFi.status());
    }

    // This is the expensive path: WIFI_MAX_RETRIES × WIFI_TIMEOUT_MS can be
    // 45 s awake at 50-140 mA without publishing anything. Recording how
    // much it cost is half of the question the ~17% of lost cycles can't
    // answer today.
    logging_write(LOG_WIFI_GIVEUP, 0, (int16_t)((millis() - wifiStartMs) / 100));
    return false;
}

// ═════════════════════════════════════════════════════════════════════════════
// MQTT connection
// ═════════════════════════════════════════════════════════════════════════════
bool connectMQTT() {
    mqtt.setServer(MQTT_BROKER, MQTT_PORT);
    mqtt.setCallback(mqttCallback);
    // 512 was too small: the telemetry payload reaches ~546 B with
    // below-zero temperatures (more digits) and the DHT22's 3 fields.
    // PubSubClient silently drops the entire publish if it doesn't fit
    // (buffer = header 5 + 2 + topic 20 + payload). 768 leaves margin for
    // the pending wind subsystem.
    mqtt.setBufferSize(MQTT_BUFFER_BYTES);

    // Short keepalive on purpose in the normal cycle — not because of the
    // client's PING (the node lives 2.2 s and never gets to send it) but
    // because of the keepalive's other effect: the broker declares a
    // session dead at 1.5 × keepalive. At 30 s that's 45 s, below the ~63 s
    // cycle, so every wake finds the client ID free. With the 60 s it used
    // to be, the expiration fell to 90 s and the previous session stayed
    // alive on every reconnection, forcing a duplicate takeover on every
    // cycle. See MQTT_KEEPALIVE_NORMAL_SEC in config.h and the telemetry
    // loss section in ../STATUS.md.
    //
    // Service mode needs the opposite and renegotiates it on its own, by
    // reconnecting (serviceMode_run) — the value that governs the broker is
    // the one that travels in the CONNECT, so changing it on an
    // already-open connection isn't enough.
    mqtt.setKeepAlive(MQTT_KEEPALIVE_NORMAL_SEC);

    // Socket timeout. Lowered from 5 s to 2 s on 2026-07-30 for energy: it's
    // the time paid in full, awake, on every cycle that fails to connect.
    //
    // The number comes from measurement, not taste. Over 30 consecutive
    // successful cycles the awake time was **2291-2293 ms**, with the
    // publish always landing around 2292: zero variance. In other words,
    // when the MQTT handshake works it takes ~46 ms, and a 5 s timeout is
    // 100× what's needed. At 2 s not a single connection that succeeds
    // today gets cut off, and it saves ~3 s on the ~27% of cycles that fail
    // (≈12 mAh/day out of an active budget of ~47).
    //
    // The risk, noted so it can be detected: in the first field capture
    // (1.3.0, a different router config and worse signal) SUCCESSFUL
    // handshakes of 2400-3200 ms were seen. That regime doesn't show up in
    // the current data, but if it came back, this timeout would cut off
    // connections that would have worked. Detectable with a level-1 log
    // capture: `LOG_MQTT_FAIL` with state -4 would show up, which are
    // nearly nonexistent today. If it happens, raise it to 4 s — that only
    // costs ~4 mAh/day relative to 2 s.
    //
    // Can't set 1.5 s: PubSubClient only takes whole seconds.
    mqtt.setSocketTimeout(2);

    const uint32_t mqttStartMs = millis();
    if (mqtt.connect(MQTT_CLIENT_ID, MQTT_USER, MQTT_PASSWORD)) {
        LOG_V("MQTT connected");
        logging_write(LOG_MQTT_OK, 0, (int16_t)(millis() - mqttStartMs));
        mqtt.subscribe(TOPIC_CMD);
        return true;
    }
    LOG_E("MQTT error: %d", mqtt.state());
    // The other half of the question: with WiFi up and this down, the cycle
    // is lost either way but the cause is completely different.
    logging_write(LOG_MQTT_FAIL, 0, (int16_t)mqtt.state());
    return false;
}

void mqttCallback(char* topic, byte* payload, unsigned int length) {
    if (strcmp(topic, TOPIC_CMD) == 0) {
        pendingCmdPayload = "";
        for (unsigned int i = 0; i < length; i++) {
            pendingCmdPayload += (char)payload[i];
        }
        cmdReceived = true;
        LOG_V("CMD received: %s", pendingCmdPayload.c_str());
    }
}

// ═════════════════════════════════════════════════════════════════════════════
// Wait for the broker's retained message
// ═════════════════════════════════════════════════════════════════════════════
Command waitForRetainedCommand() {
    cmdReceived = false;
    uint32_t start = millis();

    while (!cmdReceived && (millis() - start) < MQTT_RETAINED_WAIT_MS) {
        mqtt.loop();
        delay(20);
    }

    if (!cmdReceived) {
        LOG_V("No retained command — normal flow");
        Command none;
        none.type  = CommandType::NONE;
        none.valid = true;
        return none;
    }

    return parseCommand(pendingCmdPayload);
}

// ═════════════════════════════════════════════════════════════════════════════
// Command dispatch
// ═════════════════════════════════════════════════════════════════════════════
void handleCommand(const Command& cmd) {
    if (cmd.type != CommandType::NONE) {
        logging_write(LOG_CMD_RX, (uint8_t)cmd.type, 0);
    }

    if (!cmd.valid) {
        LOG_E("Invalid command — continuing with normal flow");
        // Clear it, for the same reason CONFIG, CALIBRATE and the default case
        // below do. This path was the one that got missed: a command the node
        // cannot parse stayed retained forever, re-read on every wake, with the
        // single retained slot jammed — no service mode, no log_on, nothing.
        //
        // Newly reachable without anyone doing it by hand: the backend can now
        // publish commands on its own, so a backend that knows a command this
        // firmware does not would wedge the slot silently. Discarding what we
        // cannot understand is the correct answer to that, and the operator can
        // always republish.
        clearRetainedCommand();
        publishTelemetry();
        goToDeepSleep();
        return;
    }

    switch (cmd.type) {

        case CommandType::NONE:
            // Normal flow: measure and sleep
            publishTelemetry();
            goToDeepSleep();
            break;

        case CommandType::MAINTENANCE:
            // Fully delegate to the service mode module
            serviceMode_evaluate(mqtt, cmd);
            // serviceMode_evaluate does not return (calls goToDeepSleep internally)
            break;

        case CommandType::PING: {
            // Respond with status and continue the normal cycle
            JsonDocument doc;
            doc["firmware"]   = FIRMWARE_VERSION;
            doc["boot_count"] = rtc_bootCount;
            doc["state"]      = "alive";
            char buf[128];
            serializeJson(doc, buf);
            mqtt.publish(TOPIC_STATUS, buf, false);
            mqtt.loop();
            delay(100);
            mqtt.publish(TOPIC_CMD, "", true);  // clear retained
            mqtt.loop();
            delay(100);
            publishTelemetry();
            goToDeepSleep();
            break;
        }

        case CommandType::REBOOT:
            LOG_V("Reboot command received");
            // Clear the retained command BEFORE restarting. Without this the
            // node reads the same {"cmd":"reboot"} again on the next wake and
            // restarts again, in a loop, until the battery runs out — the
            // command stays retained on the broker and nothing clears it.
            // Unlike PING (which clears, below) and MAINTENANCE (which
            // clears on exiting service mode), REBOOT had no way out.
            mqtt.publish(TOPIC_CMD, "", true);
            mqtt.publish(TOPIC_STATUS, "{\"state\":\"rebooting\"}", false);
            mqtt.loop();
            delay(200);
            ESP.restart();
            break;

        // CONFIG and CALIBRATE are stubs, but they still have to clear the
        // retained command: a command that runs and doesn't get cleared
        // gets read again on every wake, forever. It's the same problem
        // REBOOT had, except here nothing restarts — the node would keep
        // logging "not implemented yet" indefinitely and the retained cmd
        // would never leave the broker. Reachable from the UI's raw JSON
        // console.
        case CommandType::CONFIG:
            // TODO: implement config change in NVS
            LOG_V("Config command — not implemented yet");
            clearRetainedCommand();
            publishTelemetry();
            goToDeepSleep();
            break;

        case CommandType::CALIBRATE:
            // TODO: implement calibration routine
            LOG_V("Calibrate command — not implemented yet");
            clearRetainedCommand();
            publishTelemetry();
            goToDeepSleep();
            break;

        case CommandType::LIVE:
            // Publishes one payload through the normal path first, then hands
            // over. That first publish is not cosmetic: it is the last one that
            // carries a fresh boot_count, so the gap detector has an anchor on
            // the boundary between the sleeping cycle and the live session.
            //
            // The retained command is deliberately NOT cleared here. It is what
            // keeps the session alive across a restart — a watchdog or brownout
            // during live mode drops the node into the normal cycle, where it
            // reads this same command and re-enters through the entry checks.
            // liveMode_exit() is the only place that clears it.
            LOG_V("live command — interval %us, timeout %d min, force %d",
                  cmd.live_interval_sec, cmd.timeout_min, (int)cmd.live_force);
            publishTelemetry();
            liveMode_run(mqtt, cmd.timeout_min, cmd.live_interval_sec, cmd.live_force);
            // liveMode_run does not return (exits via deep sleep)
            break;

        case CommandType::LOG:
            // Does not enter service mode on purpose: logging has to run
            // during the normal 60 s cycles, which is exactly what needs to
            // be observed. The node applies the config, clears the retained
            // command and continues the cycle — the cost of capturing is an
            // 8-byte memcpy, so it changes nothing about consumption.
            LOG_V("log_on command — level %u, entries %u", cmd.log_level, cmd.log_entries);
            logging_configure(cmd.log_level, cmd.log_entries);
            clearRetainedCommand();
            publishTelemetry();
            goToDeepSleep();
            break;

        default:
            LOG_E("Unhandled command — normal flow");
            clearRetainedCommand();
            publishTelemetry();
            goToDeepSleep();
            break;
    }
}

// ═════════════════════════════════════════════════════════════════════════════
// Clear the retained command
// ═════════════════════════════════════════════════════════════════════════════
// An empty payload with retain=true erases the broker's retained message.
// Every command that runs has to do this, otherwise it arrives again on the
// next wake and repeats indefinitely.
void clearRetainedCommand() {
    mqtt.publish(TOPIC_CMD, "", true);
    mqtt.loop();
    delay(100);
}
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

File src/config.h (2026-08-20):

#pragma once

// ─── Firmware ─────────────────────────────────────────────────────────────────
// The real version is defined by -DFIRMWARE_VERSION in platformio.ini, per
// environment. This fallback is a sentinel, not a version: if it shows up in
// telemetry, it means the build came from an environment that forgot to
// define the flag. It used to say "1.0.0", which was a version that
// genuinely existed — a misconfigured build was indistinguishable from a
// legitimate 1.0.0 deploy.
#ifndef FIRMWARE_VERSION
  #define FIRMWARE_VERSION "0.0.0-nobuildflag"
#endif

// ─── Network ──────────────────────────────────────────────────────────────────
// Credentials: do NOT go here. They arrive via -D from `secrets.ini`, which
// is in .gitignore — see `secrets.ini.example` for the template and the two
// escaping warnings. This file is version-controlled and the repo lives on
// GitHub.
//
// The #error is deliberate, not paranoia: without it, a build missing
// secrets.ini would still compile with empty macros and flash a node that
// can't associate with anything. In a sealed enclosure out in the field,
// that gets fixed by opening the box and plugging in USB, because there
// would be no OTA either.
#if !defined(WIFI_SSID) || !defined(WIFI_PASSWORD) || !defined(MQTT_USER)  || !defined(MQTT_PASSWORD) || !defined(OTA_PASSWORD)
  #error "Missing credentials: copy secrets.ini.example to secrets.ini and fill it in."
#endif
// Timeout per association attempt. Lowered from 15 s to 5 s on 2026-07-31,
// with the missing data point: `STATUS.md` had a note to revisit this budget
// but asked to first "capture a window with worse signal", because the
// worst case of 3 × 15 s = 45 s had never been observed. A level-1 log
// capture over ~830 cycles showed it **twice** (boots 668 and 1074): three
// consecutive failed attempts and `WIFI_GIVEUP` at 45.9 s awake, against the
// 2.3 s of a healthy cycle.
//
// The imbalance is the same one the MQTT socket timeout had: a successful
// association takes **275 ms** (measured, dozens of samples with minimal
// variance) and the timeout was 15,000. And the codes it fails with are
// "this isn't going to work" states, not "it's taking a while" ones —
// `WL_NO_SSID_AVAIL` and `WL_DISCONNECTED`, not a handshake in progress.
//
// 5 s and not less because attempt 1 uses the cached BSSID and the ones
// after it **scan**: a scan of the 13 channels plus association can
// legitimately run 2-4 s. Cutting below that would cut off retries that do
// work — and they do: on boot 1057 attempt 1 failed and attempt 2 connected.
//
// The savings are modest and shouldn't be overstated: ~1.4 mAh/day out of an
// active budget of ~47. What it really prevents is a 45 s awake spike on a
// battery that today closes negative by mid-morning.
#define WIFI_TIMEOUT_MS     5000
#define WIFI_MAX_RETRIES    3

// ─── WiFi transmission rate ───────────────────────────────────────────────────
// Forces 802.11b mode (1 / 2 / 5.5 / 11 Mbps) instead of letting the rate
// control climb to OFDM (11g/n, up to 72 Mbps).
//
// The reason came from the sniffer, and it's direct evidence, not a theory.
// Over a 6844-frame capture with the sniffer next to the AP:
//
//   frames TOWARD the node captured ........ 4550
//   management frames FROM the node (at 1 Mbps) .. captured fine
//   DATA frames FROM the node (OFDM) ........ ZERO, not one in an hour
//
// Same distance, same antenna, same moment. The only thing that changes
// between the ones that decode and the ones that don't is **the modulation
// rate**. In other words, the node's high-rate transmissions are at the edge
// of what's demodulable, and the AP —which is a better receiver— gets them
// but pays 16-37% in retries.
//
// At 1-11 Mbps the required sensitivity is 5-10 dB lower than OFDM: exactly
// the margin that was missing. The cost is airtime (a 660 B frame takes
// 0.5 ms at 11 Mbps against 0.1 ms at 54), which on a node transmitting a
// handful of frames per minute shows up in neither energy nor channel use.
//
// Set to 0 to go back to the default behavior.
#define WIFI_FORCE_11B      1
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

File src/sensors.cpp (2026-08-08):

#include <math.h>
#include <Adafruit_SHT31.h>
#include <Adafruit_BMP085.h>
#include <Adafruit_INA219.h>
#include <OneWire.h>
#include <DallasTemperature.h>
#include <DHT.h>

#include "sensors.h"
#include "config.h"

// ─── Driver objects ───────────────────────────────────────────────────────────
static Adafruit_SHT31  sht31;
static Adafruit_BMP085 bmp;
static Adafruit_INA219 ina219_solar(INA219_SOLAR_ADDR);
static Adafruit_INA219 ina219_system(INA219_SYSTEM_ADDR);

static OneWire           _oneWire(PIN_DS18B20);
static DallasTemperature _ds18b20(&_oneWire);
static DHT               _dht(PIN_DHT22, DHT22);

// ─── Initialization state ─────────────────────────────────────────────────────
static bool _sht31_ok   = false;
static bool _bmp_ok     = false;
static bool _solar_ok   = false;
static bool _system_ok  = false;
static bool _ds18b20_ok = false;

// ─── Rails ────────────────────────────────────────────────────────────────────
// Moment the rails delivered power, to anchor the DHT22 warmup. In .bss, so
// they start at zero/false on every boot — including a deep sleep wake,
// where only RTC memory survives.
static uint32_t _rail_on_ms = 0;
static bool     _rails_on   = false;

// =============================================================================
//  Battery monitor for service mode
// =============================================================================
// See sensors.h for the why: sensors_init() does not run in service mode, so
// without this the heartbeat can't report voltage. Only touches the system
// INA219 (0x40), which is on the always-powered I2C bus — turns on no rail.

bool sensors_initSystemMonitor() {
    if (!_system_ok) {
        _system_ok = ina219_system.begin();
    }
    return _system_ok;
}

float sensors_readSystemVoltage() {
    if (!_system_ok) return NAN;
    return ina219_system.getBusVoltage_V();
}

// See sensors.h for the why behind the guard: powerSave() does not check
// i2c_dev, and there are paths that reach sleep without having initialized
// anything.
void sensors_sleepMonitors() {
    if (_solar_ok)  ina219_solar.powerSave(true);
    if (_system_ok) ina219_system.powerSave(true);
}

// =============================================================================
//  Initialization
// =============================================================================

// Idempotent on purpose: setup() calls it right at startup, so the DHT22
// warmup runs in parallel with WiFi+MQTT instead of in series. But
// sensors_init() calls it again too, so it stays correct even if someone
// adds a path that reaches init without going through setup(). The
// timestamp is the one from the first call — the moment the rail actually
// delivered power.
void sensors_railsOn() {
    if (_rails_on) return;

    // TODO [low power]: turn off Rail B at Tier 2 and Rail A at Tier 3
    //   based on battery threshold — see battery.h
    pinMode(PIN_RAIL_A, OUTPUT); digitalWrite(PIN_RAIL_A, HIGH);
    pinMode(PIN_RAIL_B, OUTPUT); digitalWrite(PIN_RAIL_B, HIGH);

    _rail_on_ms = millis();   // reference point for the DHT22 warmup
    _rails_on   = true;
}

bool sensors_init() {
    // No-op if setup() already turned them on, which is the normal case.
    sensors_railsOn();

    // ── DS18B20 ───────────────────────────────────────────────────────────────
    _ds18b20.begin();
    _ds18b20.setResolution(9);   // ~93 ms conversion
    _ds18b20_ok = (_ds18b20.getDeviceCount() > 0);

    // ── DHT22 ─────────────────────────────────────────────────────────────────
    _dht.begin();

    // ── Pulse sensors (always-on) — pins configured, data deferred ───────────
    // TODO [pulses]: implement accumulated counting in RTC memory
    pinMode(PIN_ANEMOMETER, INPUT_PULLUP);
    pinMode(PIN_RAIN_GAUGE,  INPUT_PULLUP);

    // ── I2C sensors (Wire already initialized in setup() before reaching here) ─
    _sht31_ok  = sht31.begin(0x44);
    _bmp_ok    = bmp.begin();
    _solar_ok  = ina219_solar.begin();
    _system_ok = ina219_system.begin();

    // ── DHT22 warmup ──────────────────────────────────────────────────────────
    // Measured from when Rail B delivers power, NOT from boot. With the
    // rail-on moved to the start of setup() (1.5.0), by the time execution
    // reaches here WiFi, MQTT and the retained-command wait have already
    // happened, so most of the warmup has already elapsed and this delay
    // ends up a few hundred ms instead of a full 2 s. It goes at the end of
    // init so the I2C bus and DS18B20 time also counts as part of the
    // warmup instead of adding on top.
    uint32_t elapsed = millis() - _rail_on_ms;
    if (elapsed < DHT_WARMUP_MS) {
        delay(DHT_WARMUP_MS - elapsed);
    }

    LOG_V("Rails A:HIGH B:HIGH | DS18B20:%s | SHT31:%s BMP:%s INA_sol:%s INA_sys:%s",
        _ds18b20_ok ? "OK" : "ERR",
        _sht31_ok   ? "OK" : "ERR",
        _bmp_ok     ? "OK" : "ERR",
        _solar_ok   ? "OK" : "ERR",
        _system_ok  ? "OK" : "ERR");

    return _sht31_ok && _bmp_ok && _solar_ok && _system_ok;
}

// =============================================================================
//  Reading
// =============================================================================
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

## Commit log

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2026-03-25 FOTA e infra, base
    [partitions_ota.csv]
2026-03-25 Bugfix a comando ping
    [main.cpp]
2026-03-25 Bugfix: flush MQTT before WiFi disconnect en deep sleep
    Agrega mqtt.disconnect() + delay(200) antes de WiFi.disconnect(true)
    para asegurar que lwIP transmita el paquete PUBLISH antes de que se
    corte la conexion. Esto corrige la perdida de mensajes de telemetria
    en el ciclo de wake normal.
    [main.cpp]
2026-03-25 Integración de sensores reales (SHT31, BMP085, INA219 x2)
    - Nuevo módulo sensors.h/.cpp con SensorData struct, sensors_init() y sensors_read()
    - SHT31: temperatura principal y humedad
    - BMP085: temperatura de referencia, presión local y QNH (780m SNM)
    - INA219 x2: voltaje, corriente y potencia del panel solar (0x41) y sistema (0x40)
    - publishTelemetry() reemplaza stub con lecturas reales; campos fallidos se omiten del JSON
    - config.h: agrega ALTITUDE_M, INA219_SOLAR_ADDR, INA219_SYSTEM_ADDR
    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
2026-03-25 Bugfix: mover sensors_init() fuera del camino crítico de boot
    sensors_init() se movió desde el inicio de setup() a después de connectMQTT(),
    justo antes de handleCommand(). Así, si un sensor cuelga el I2C (watchdog), el
    device igual puede entrar en service mode y recibir un OTA. Los sensores solo
    son necesarios para publishTelemetry(), no para service mode ni reboot.
    [main.cpp]
2026-03-25 Agregar flags de estado de sensores al payload de telemetría
    Publica sht31_ok, bmp_ok, solar_ok y system_ok en cada ciclo para
    permitir diagnóstico remoto sin necesidad de acceso serial/USB.
2026-03-25 Bugfix: aumentar buffer MQTT a 512 bytes
    El payload de telemetría con sensores reales supera el límite default de
    PubSubClient (256 bytes), causando que mqtt.publish() falle silenciosamente.
    setBufferSize(512) lo resuelve.
    [main.cpp]
2026-03-25 Optimización: cachear canal WiFi en RTC memory
    Guarda canal y BSSID en RTC_DATA_ATTR tras cada conexión exitosa.
    En el siguiente wake, conecta directamente sin escanear canales,
    reduciendo el tiempo de conexión de ~3-5s a <1s. Si falla con el
    caché, lo invalida para que el próximo intento escanee normalmente.
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2026-03-25 Mejora: reintentos de conexión WiFi (hasta WIFI_MAX_RETRIES=3)
    El primer intento usa el canal cacheado (rápido). Si falla, los
    siguientes hacen scan completo. Agrega WIFI_MAX_RETRIES en config.h.
2026-04-04 Diagramas PCB
    [Aux PCB - Estación Meteorológica - IoT_v1.2.2.fzz, Aux PCB - Estación Meteorológica - IoT_v1.2.fzz, Main PCB - Estación Meteorológica - IoT_v1.2.fzz]
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2026-04-18 Fix DHT issue, attempt 1
    [sensors.cpp]
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2026-07-11 Actualizar PCB Aux v1.2.2, agregar iteraciones Main PCB v1.3/v1.4
    Documenta hardware y conexiones actuales en componentes_y_conexiones.md
    (rev 2.0, ESP32-C3 SuperMini, sensores I2C/analogicos y monitoreo solar).
    [Aux PCB - Estación Meteorológica - IoT_v1.2.2.fzz, Main PCB - Estación Meteorológica - IoT_v1.3.fzz, Main PCB - Estación Meteorológica - IoT_v1.4.fzz]
2026-07-11 Consolidar diseño de PCB desde el repo main
    Los exports de fabricacion (etch/mask/silk PDF, SVG) que vivian en
    PCB/ en el repo main se mueven aca, junto a los .fzz fuente que ya
    estaban en este repo. Este repo pasa a ser la fuente unica para todo
    el diseño de hardware.
2026-07-11 Actualizar estado de hardware y pipeline con contexto migrado de la UI
    - componentes_y_conexiones.md: estado actual en campo, DHT11 removido/
    DHT22 pendiente, AS5600 en duda + alternativa optica Gray code
    - Readme.md: topologia real del pipeline completo (NAS, N8N, InfluxDB,
    Grafana), reemplaza la seccion "proximos servicios" que ya estaba
    vieja
    - aprendizajes_y_roadmap.md (nuevo): subsistema de viento, aprendizajes
    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
2026-07-11 Documentar PCB v2: fabricacion casera FR4 y plan de proteccion
    Conecta la carpeta PCB/ (exports Fritzing v1.4/v1.2.2) con la build
    fisica en curso. Agrega el plan de aplicacion de flux protector +
    barniz dielectrico (enmascarando headers hembra antes de barnizar,
    instalando modulos enchufables recien despues de curar).
2026-07-23 Documentar orientacion de BC337 y JST en PCB v2
    - Footprint TO92 de Fritzing: la D de la serigrafia es inconsistente con el
    orden C-B-E de los pads. Un BC337 real insertado segun la panza queda con
    colector y emisor cruzados. Cobre y esquematico son correctos.
    - Regla de armado: insertar con la parte plana al reves de la serigrafia
    - Notas de diagnostico: el dropdown EBC no sirve como fix, sintoma electrico
    del modo activo inverso, y verificacion con tester en modo diodo
    - hFE de la unidad montada en Main v1.4: 226
    - JST: aviso de orientacion tras encontrarlos 180 grados invertidos
2026-07-25 Documentar reemplazo fisico DHT11 -> DHT22 (firmware pendiente)
    Transplante del sensor DHT22 pelado al modulo Sunfounder original del
    DHT11 (muerto por falla cronica), reutilizando pull-up/filtro/footprint
    del modulo. Sin cambios de cableado ni PCB. Falta reactivar el firmware.
2026-07-25 Mejora serigrafía PCBs
    [Aux PCB - Estación Meteorológica - IoT_v1.3.fzz, Main PCB - Estación Meteorológica - IoT_v1.5.fzz]
2026-07-25 Reactivar sensor DHT como DHT22 y corregir dos bugs latentes
    El DHT11 fue reemplazado fisicamente por un DHT22 (mismo modulo Sunfounder,
    mismo pin GPIO0, sin cambios de cableado). Se reactiva el codigo que estaba
    comentado y se lo adapta al DHT22:
    - Driver con tipo DHT22, PIN_DHT11 -> PIN_DHT22 (GPIO0, sin cambio de pin).
    - Se eliminan las constantes de calibracion de humedad: corregian el sesgo
    del DHT11 defectuoso y volverian a sesgar al DHT22, calibrado de fabrica.
    - Reintento espaciado por DHT_RETRY_INTERVAL_MS (2s, periodo minimo de
    muestreo del DHT22) y con una sola trama forzada en vez de dos seguidas.
    - Los campos MQTT conservan el nombre dht11_* a proposito: renombrarlos
    part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
    [config.h, main.cpp, sensors.cpp]
2026-07-25 Separar OTA en dos entornos explicitos y bumpear a 1.1.0
    El unico env:ota_upload extendia env:development, asi que todo deploy por
    OTA mandaba el build de debug sin que se notara. Con LOG_LEVEL=2 el setup()
    quema 2s fijos en delay(2000) por cada wake, encima del warmup del DHT22 —
    en un ciclo de 60s es una porcion grande del tiempo despierto, sin ningun
    beneficio en campo. El nodo venia corriendo asi (la telemetria reportaba
    1.0.5-dev).
    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
2026-07-25 STATUS: AS5600 vuelve a ser candidato fuerte para direccion de viento
    El modulo vino con un iman chico no notado antes, lo que corrige la
    conclusion previa de imanes disponibles incompatibles. En validacion
    de banco con Arduino Mega: primero a mano sin la veleta, despues PoC
    con la veleta montada. Optica (TCRT5000) queda como plan B.
2026-07-26 system_v en el heartbeat de service mode y fix del loop de reboot
    Durante service mode el nodo quedaba invisible en cuanto a batería, que es
    justo cuando importa: se mantiene despierto a 50-140 mA sin deep sleep que le
    permita recuperar tensión, y el riesgo real de flashear con la batería baja no
    es quedarse sin capacidad sino el sag bajo carga hasta el brownout a mitad de
    escritura. sensors_init() no corre en service mode (el nodo retoma la sesión sin
    pasar por el ciclo normal), así que los INA219 nunca se inicializaban.
    sensors_initSystemMonitor() / sensors_readSystemVoltage() inicializan y leen solo
    el INA219 de sistema (0x40), sin encender Rail A ni Rail B: los INA219 cuelgan del
    b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
    [main.cpp, sensors.cpp]
2026-07-26 Bump de firmware a 1.2.0 / 1.2.0-dev
    Los cambios de la sesión anterior (system_v en el heartbeat de service mode, más el
    fix del loop de reboot) se quedaron sin bump, así que el campo firmware de la
    telemetría no permitía distinguir si el OTA había entrado.
    Bump menor: agrega una feature compatible hacia atrás más un bug fix. El string
    mide lo mismo que 1.1.0, así que no mueve el tamaño del payload — que igual tiene
    255 B de margen sobre el buffer.
    Verificado que el string queda embebido en los dos binarios, no solo que compilan.
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2026-07-26 El timeout de service mode ahora acota de verdad
    Encontrado probando con timeout_min=1: el log de status mostraba tres
    service_mode_active sin ningún service_mode_ended entre medio. El nodo no
    completaba las sesiones, las reiniciaba.
    La cadena: se cae MQTT en medio de la sesión, el loop hacía break sin reintentar
    (pese a que el log decía "reintentando"), y caía en serviceMode_exit con reason
    mqtt_disconnected. Esa salida limpia el flag de RTC pero tiene el clear del
    retenido y el publish del ended detrás de un if (mqtt.connected()) — con el broker
    caído no hace ninguna de las dos, en silencio. Deep sleep 60 s, despierta, el flag
    ya está en false, flujo normal, lee el maintenance q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
    [config.h]
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2026-07-28 Diseño del sistema de logs del nodo
    Documento de contratos para los tres repos, previo a implementar. El problema
    que resuelve: el nodo en campo no tiene observabilidad — LOG_LEVEL=0 compila
    los macros a no-op y el unico sink es Serial por USB dentro de la caja
    estanca. El disparador concreto es el ~17% de ciclos que no publican, sin
    forma de saber si falla WiFi o MQTT.
    Decisiones principales:
    - Logging activable a demanda, no permanente. Capturar es un memcpy de 8 B en
    RTC memory, o sea energeticamente gratis; el unico costo real es el dump,
    que es operador-iniciado.
    - Ring en RTC memory. El C3 tiene 8176 B y nada mas (verificado en memory.ld),
    asi que la captura se mide en horas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
2026-07-28 La captura sobrevive a un reinicio del nodo, y tres arreglos menores
    Revision previa al flasheo del 1.3.0.
    El hallazgo principal: todo el estado del logging usaba RTC_DATA_ATTR, que segun
    esp_attr.h conserva el valor "during a deep sleep / wake cycle" — no despues de
    un restart. Eso significaba que un panic, un watchdog, una brownout o un comando
    reboot borraban la captura entera Y ponian el nivel en 0.
    Lo grave no era perder los datos sino que era silencioso: la captura se
    desarmaba sola y la UI mostraba "Captura detenida" sin explicacion. Y con una
    ironia: el esp_reset_reason() del evento de boot existe para distinguir brownout
    de panic, pero esa entry nunca se escribia, porque cuando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
    [main.cpp]
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2026-07-29 Bump a 1.3.1 por el fix de LOG_PUBLISH_FAIL
    El cambio anterior —distinguir "no entra en el buffer" de "conexion caida"—
    quedo sin bumpear la version. Es un patch: corrige un diagnostico equivocado sin
    agregar ni sacar nada.
    Importa mas que un bump cosmetico porque toca la plantilla de un codigo de log,
    o sea el diccionario. La huella FNV que valida el estado persistido va a dejar
    de coincidir, asi que al flashear se descarta cualquier captura en curso — que
    es exactamente lo que tiene que pasar: entries viejas leidas con un diccionario
    nuevo saldrian mal etiquetadas.
    El string mide lo mismo que 1.3.0, asi que no mueve el tamaño del payload.
    Compila limpio en production y development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
2026-07-29 1.4.0: los INA219 duermen en power-down entre ciclos
    Los dos INA219 cuelgan del bus 3V3, que el regulador del ESP32 sigue
    alimentando durante el deep sleep, asi que venian convirtiendo las ~57 s
    por ciclo en que nadie los lee: ~0,7-1 mA cada uno por datasheet, contra
    los ~6 uA del modo power-down.
    Con el system_mA medido en campo (51,2 mA de mediana en la ventana
    despierta, no los ~100 mA que se estimaban), el consumo activo son
    ~68 mAh/dia y estos dos chips estaban en el mismo orden de magnitud.
    powerSave() de la libreria usa i2c_dev sin chequear null, y el camino de
    fallo de red entra a deep sleep sin pasar por sensors_init() — de ahi el
    guard por _solar_ok/_system_ok, que sin el crash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
    [main.cpp, sensors.cpp]
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2026-07-29 1.5.0: el warmup del DHT22 corre en paralelo con la red
    El rail-on vivia dentro de sensors_init(), que corre despues de WiFi,
    MQTT y la espera del comando retenido. Los ~2 s de estabilizacion del
    DHT22 se pagaban enteros al final del ciclo, con la radio asociada
    consumiendo: eran el 61% de los 3,3 s de ventana despierta medidos en
    campo el 2026-07-28.
    Adelantado al arranque del ciclo normal, el warmup transcurre mientras
    el nodo hace trabajo que tenia que hacer igual. Estimado: 3,3 s -> ~2,2 s
    de despierto, ~21 mAh/dia con el system_mA de 51,2 mA medido en campo.
    sensors_railsOn() es idempotente y sensors_init() la vuelve a llamar, asi
    que el init sigue siendo correcto por si algun camino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
    [main.cpp, sensors.cpp]
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2026-07-29 1.6.0: keepalive corto en el ciclo normal, largo solo en service mode
    El keepalive no gobierna solo el PINGREQ del cliente: define tambien cuanto
    tarda el broker en dar por muerta una sesion (1.5x). Con 60 s eso son 90 s,
    mas que el ciclo de ~63 s del nodo, asi que cada reconexion encontraba la
    sesion anterior viva y forzaba un takeover por client-ID duplicado en todos
    los ciclos. Es la hipotesis principal del 38-42% de payloads perdidos.
    Ciclo normal a 30 s (expiracion a 45 s, por debajo de los 57 s del peor caso
    del timer de deep sleep): el nodo vive 2,2 s, asi que su propio PINGREQ nunca
    se dispara y bajarlo no cuesta nada del lado del cliente.
    Service mode conserva 60 s, que es donde e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
    [config.h, main.cpp]
2026-07-29 1.7.0: balizas de uplink para acotar donde muere el camino al broker
    Medido hoy desde un tercer punto de vista — los contadores $SYS del propio
    Mosquitto, que se incrementan en handle__publish antes de rutear — sobre 16
    ciclos de 1.5.0 con 38% de perdida:
    ciclo entregado : ~596 B de ingreso al broker
    = CONNECT 67 + SUBSCRIBE 21 + PUBLISH 503 + DISCONNECT 2
    ciclo perdido : ~92 B
    = CONNECT + SUBSCRIBE, y NADA mas
    Y publish/messages/received subio +1 en los 10 entregados y 0 en los 6
    perdidos. O sea que los PUBLISH perdidos nunca entraron al broker: no es un
    descarte interno ni un problema de entrega a los suscriptores.
    Como TCP entrega en or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
    [config.h, main.cpp]
2026-07-29 1.8.0: apagar el modem sleep de WiFi, y balizas off
    La medicion de hoy movio el diagnostico una capa entera para abajo. Sondeando el
    nodo con ICMP cada 150 ms mientras se median las llegadas al broker, la ventana
    en que el nodo responde predice exactamente hasta donde llega el ciclo:
    0-180 ms alcanzable -> ni siquiera conecta al broker
    470-1100 ms alcanzable -> conecta, no llega a publicar (el publish va a 2,3 s)
    2150-2700 ms alcanzable -> publica y cierra limpio
    O sea que el nodo deja de responder a mitad de su ventana despierta, en los DOS
    sentidos: no es MQTT, no es el broker, no es TCP. Se le muere la asociacion WiFi
    a un tiempo variable despues de asociarse, y todo lo demas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
    [config.h, main.cpp]
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2026-07-30 1.9.0: el nodo reporta como cerro el ciclo anterior
    Los ciclos que se pierden no publican nada, asi que desde afuera no se puede
    saber que vio el nodo. Pero el ciclo SIGUIENTE publica ~60% de las veces y la
    RTC memory sobrevive al deep sleep: alcanza con guardar la foto del enlace en el
    ultimo instante del ciclo y mandarla despues.
    Contesta la pregunta que decide cual es el arreglo: al final de un ciclo
    perdido, el nodo SABE que se quedo sin enlace o cree que sigue asociado?
    pv_st = 3 (WL_CONNECTED) -> el driver esta sordo y mudo creyendose conectado,
    y hace falta confirmacion de entrega en banda
    pv_st = 5 o 6 -> el nodo lo sabe, y alcanza co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
    [main.cpp]
2026-07-30 tools/wifi-sniffer: captura 802.11 en modo promiscuo
    Proyecto PlatformIO aparte, para una placa de banco (ESP32-S3), no para el nodo.
    Sale del punto muerto al que llegamos: el enlace del nodo se muere a mitad de
    ciclo en los dos sentidos mientras su driver sigue reportando WL_CONNECTED con
    RSSI normal, y ya se descartaron con medicion el broker, MQTT, TCP, el tamano de
    frame, el margen de RF, el modem sleep, el band steering y el 802.11ax.
    Lo que falta esta en el aire y no hace falta descifrar nada: el bit de Retry va
    en la cabecera MAC y los deauth/disassoc son management frames en claro con su
    reason code. Tres ramas mutuamente excluyentes:
    el nodo sigue transmitiendo con Retry=1 y sin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
    [main.cpp]
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2026-07-30 wifi-sniffer: salida por UART0, latido, y arreglo de la cola
    Tres cosas que salieron de intentar capturar la salida y no ver nada.
    1. La app no imprimia porque la placa estaba arrancando en modo descarga:
    `rst:0x15, boot:0x23 (DOWNLOAD(USB/UART0))`, esperando un flasheo que nunca
    llegaba. Lo causo tocar RTS a mano para "resetearla". En el USB-Serial-JTAG
    del S3, DTR y RTS gobiernan IO0 y EN con logica propia del periferico, asi
    que cualquier toque se interpreta como secuencia de arranque — y el monitor
    de PlatformIO probablemente hacia lo mismo al abrir. Encima el dispositivo se
    re-enumera en cada reset, asi que un monitor abierto de antes queda con un
    handle muerto.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
    [main.cpp]
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2026-07-30 topcap: documentar que las tramas traen FCS
    El sig_len del modo promiscuo del ESP32 incluye los 4 bytes de FCS al final
    (verificado: un ACK sale de 14 B = 10 de cabecera + 4). Sin marcar "Assume
    packets have FCS" en las preferencias de IEEE 802.11, Wireshark los interpreta
    como cuerpo y da todas las tramas por malformadas.
    Pipeline validado punta a punta contra una captura parcial: 187 tramas, pcap
    bien formado, DLT 105, y los tipos parsean correctamente (data, ack, block-ack,
    qos-data, rts/cts, action). Cero truncadas con PCAP_SNAPLEN 600.
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2026-07-31 tools/brokerprobe: versionar el instrumental de la investigacion
    STATUS.md los referenciaba como "en el scratchpad de la sesion", que es un
    directorio temporal y se iba a evaporar con la sesion.
    Se versionan porque cambiaron el costo de medir: antes saber cuanta telemetria
    se perdia costaba una captura de logs, una sesion de service mode y una
    transferencia paginada — una noche y una operacion cara. Con esto son 35 minutos
    desde la LAN sin tocar el nodo.
    El README documenta lo que no es obvio: por que los contadores $SYS contestan
    algo que un tercer suscriptor no puede (se incrementan antes de rutear), por que
    el sondeo ICMP usa la clase de .NET y no ping.exe (intervalo fijo de 1 s), y p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
2026-08-02 Fix a remaining Spanish comment in board_config.h
2026-08-02 Translate tools/brokerprobe (Go, Python, PowerShell) to English
    Diagnostic tooling used to investigate the WiFi/MQTT telemetry loss
    issue: main.go, analyze.py, linkstate.py, crossref.py, serialcap.ps1,
    pingstorm.ps1. Includes console output strings, not just comments,
    since these are read directly by whoever runs the tool. tools/brokerprobe/README.md
    stays in Spanish (documentation, out of scope).
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2026-08-08 1.14.0: DHT22 warmup 2000 -> 1300 ms
    Since 1.5.0 the warmup is the term that sets the floor on the awake window
    (awake = max(network path, DHT_WARMUP_MS) + sensor reads), so every ms cut
    here comes off the cycle almost 1:1. 2000 ms was 2x the AM2302 datasheet
    minimum; 1300 keeps 30% margin.
    Estimated ~750 ms less awake time, ~15 mAh/day at the 51.2 mA measured in
    the field. Going below ~1270 ms buys almost nothing: the network path takes
    over as the dominant term.
    Three properties that bound the risk, all documented at the constant:
    - The delay is max(elapsed since rail-on, DHT_WARMUP_MS), so the sensor can
    never get less settling time than the network path took.
    - A failed read costs 20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
    [config.h]
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2026-08-08 Live mode: force flag to exercise the mode without sun
    {"cmd":"live","interval_sec":5,"timeout_min":15,"force":true}
    Skips the panel-voltage floor and nothing else, so the mode can be tested at
    night or on the bench — solar_v sits near pack voltage there and would end the
    session in 3 strikes, which is exactly the scenario a test button hits.
    The non-obvious part is the ceiling. Forcing removes the floor that normally
    ends a session that should not be running, leaving the battery floor as the
    only condition-based exit — and reaching 3.90 V from ~4.05 V under a ~70 mA
    load takes on the order of 6 h, because the LiPo curve is flat right there. A
    forced session could therefore burn a thir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
    [config.h, main.cpp]
2026-08-08 Live mode: five fixes from the review pass
    1. The budget undercounted. `elapsed` was read at the top of the loop but the
    floor exits used it after publishTelemetry(), which costs ~250 ms normally
    and ~2.3 s when the DHT22 retries. rtc_liveElapsedSec therefore accumulated
    less than each session really consumed — a safety ceiling being wrong in the
    permissive direction. Recomputed at every exit point.
    2. The budget reset even when the clear failed. mqtt.publish() of the empty
    retained payload returns a bool that was ignored, so a failed write still
    zeroed the accumulator and the re-entry got a full budget — the exact defect
    the accumulator exists to prevent. Now gated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
    [main.cpp]
2026-08-08 1.16.0: live mode publishes a session heartbeat
    A session only ever published two status messages, one on entry and one on
    exit. The backend caches the last status, so anyone opening the dashboard
    mid-session read "live_mode_active, elapsed_s 0, seq 0" no matter how long it
    had really been running — and there was no way at all to see how much of the
    budget was left. Service mode has published remaining_sec in its heartbeat
    since it was written; live mode was missing the equivalent.
    live_mode_alive every LIVE_HEARTBEAT_SEC (30 s, same as service mode) with
    elapsed_s, remaining_s, seq and system_v. The entry status now carries
    remaining_s too.
    It goes in status rather than in the telemetry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
    [config.h]
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2026-08-09 1.17.0: un comando invalido tambien limpia el slot retenido
    El camino !cmd.valid cortaba antes del switch sin limpiar, mientras CONFIG,
    CALIBRATE, LOG y el default si lo hacen. Un comando que el nodo no puede
    parsear quedaba retenido para siempre: releido en cada wake, con el unico slot
    retenido trabado — sin service mode, sin log_on, sin nada. Es la misma clase de
    bug que ya se arreglo tres veces en este firmware; este camino quedo afuera.
    Recien alcanzable sin que nadie lo publique a mano: desde el backend 1.3.0 la
    automatizacion de live mode puede publicar comandos sola, asi que un backend
    que conozca un comando que este firmware no wedgearia el slot en silencio.
    Descartar lo que no se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
    [main.cpp]
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2026-08-09 Relevar el volumen de InfluxDB: el disco no es el limite, el barrido si
    Con live 7 h en dias soleados son 4,3x el ritmo actual — no 12x, porque live
    se auto-limita a las horas de excedente. ~170 MB/ano, ~1,7 GB en 10 anos:
    0,04% del disco de 4 TB. Aunque la estimacion se equivoque por 10x, sigue
    siendo irrelevante.
    Lo que escala mal es escanear millones de puntos de 5 s para un grafico de
    rango largo. Queda anotado el disparador: si un dashboard de rango largo
    empieza a tardar, la respuesta es downsampling, no borrar datos ni achicar
    live mode.
    Mas dos cosas del mismo relevamiento: la retencion es infinita (probablemente
    correcto para una estacion, pero que sea eleccion consciente) y la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
